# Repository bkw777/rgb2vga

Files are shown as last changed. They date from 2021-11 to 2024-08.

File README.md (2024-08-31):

# rgb2vga
Convert 15khz RGB to 31khz VGA

Uses Altera DE0-Nano FPGA development board to convert analog 15Khz RGB signal to VGA 31Khz 256 color.

This is a modified version of the original [RGB2VGA by Luis Felipe da Costa Antoniosi](https://sites.google.com/site/tandycocoloco/fpga-rgb2vga).  
<!-- (Archived original site [archive.org](https://web.archive.org/web/https://sites.google.com/site/tandycocoloco/rgb2vga)) -->

The electronics and fpga code are the same as the original.

The resistor values are from [Roger Taylor](http://www.cococommunity.net/vga-for-the-coco-3/).

The physical layout is changed to make a more compact package and to build-in the two modifications described in the original docs.

The schematic and pcb layout are re-drawn from scratch in KiCad to provide editable source files.

The VHDL source is just a fork of [the original](https://github.com/lfantoniosi/rgb2vga) but with all of the non-source files cleaned out.  
The VHDL does compile and you can generate a new working rgb2vga.jic from it. But as noted by Roger Taylor, you may want to use the original JIC file from Luis anyway because it may be more stable. There is a preseved copy of Luis's original rgb2vga.jic in [vhdl/Original_JIC](vhdl/Original_JIC).

The enclosure is mine, and the OpenSCAD source is included.

Video showing v003 in action.  
(https://youtu.be/MPYQRHWyUGA)

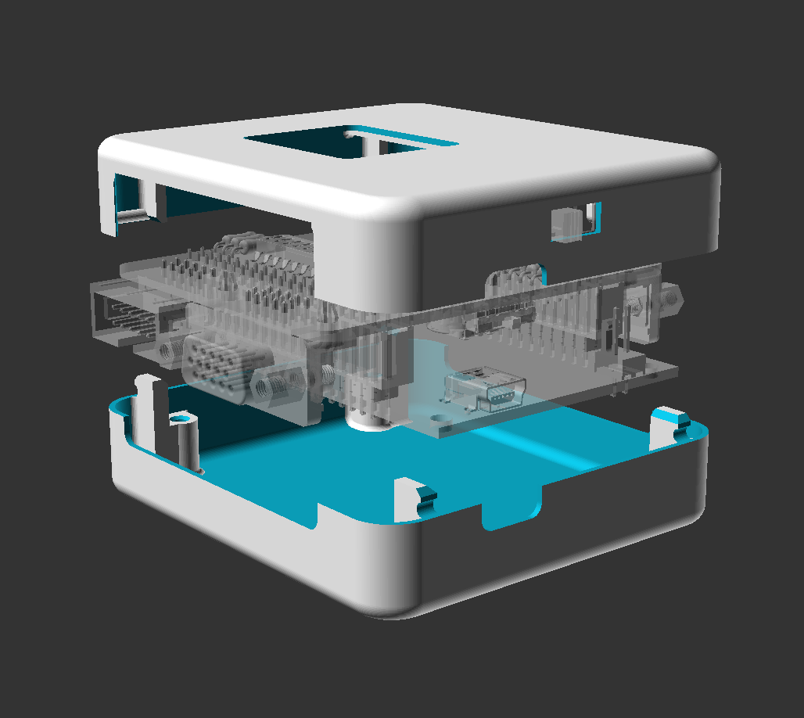
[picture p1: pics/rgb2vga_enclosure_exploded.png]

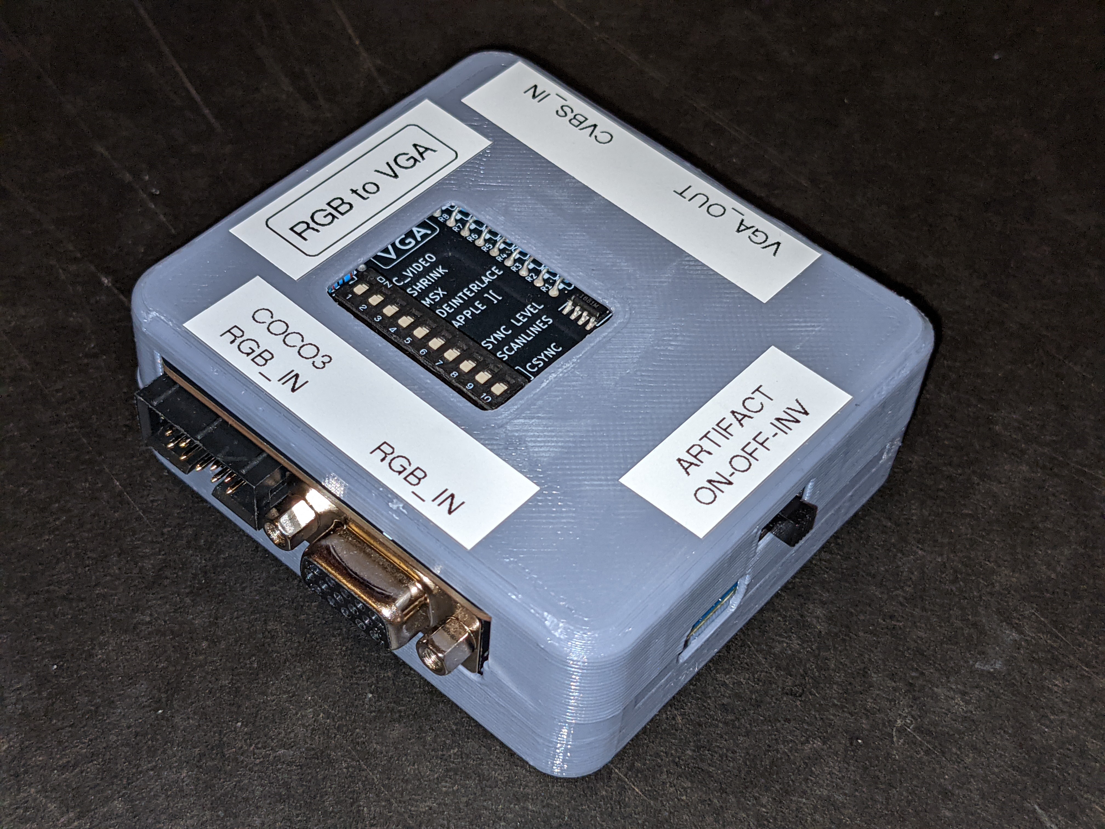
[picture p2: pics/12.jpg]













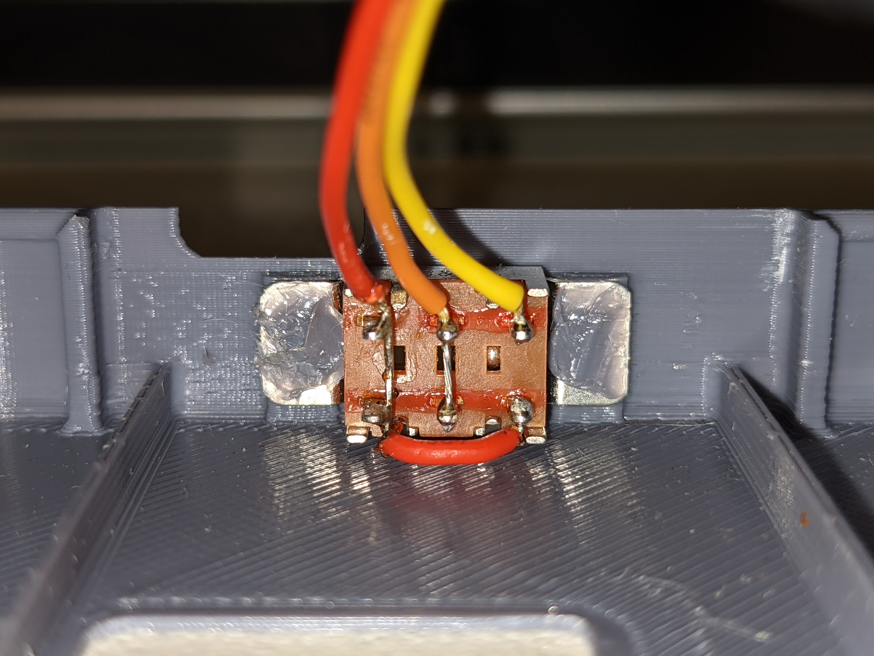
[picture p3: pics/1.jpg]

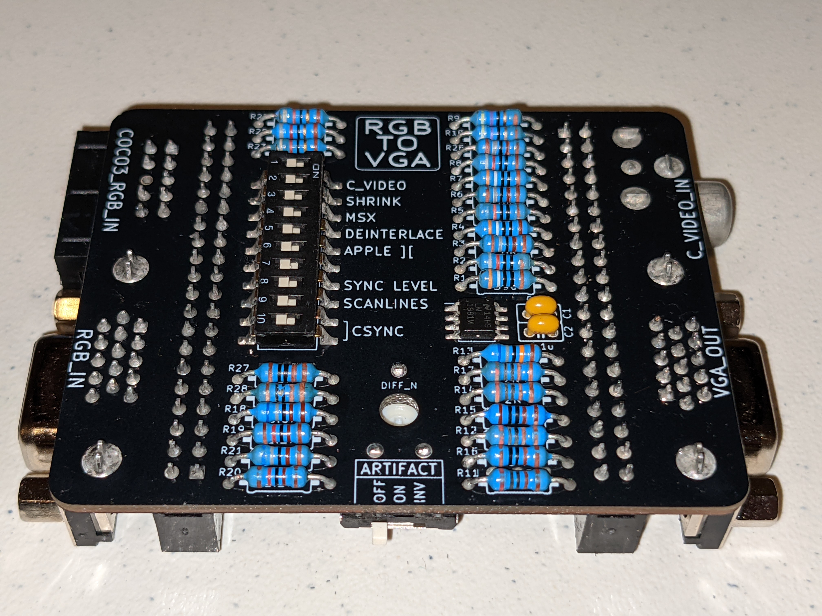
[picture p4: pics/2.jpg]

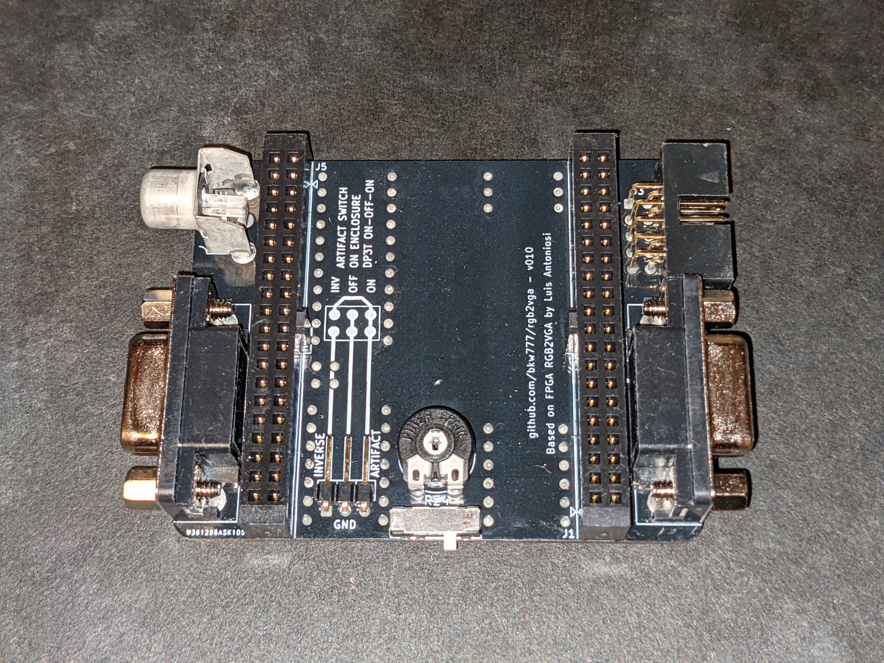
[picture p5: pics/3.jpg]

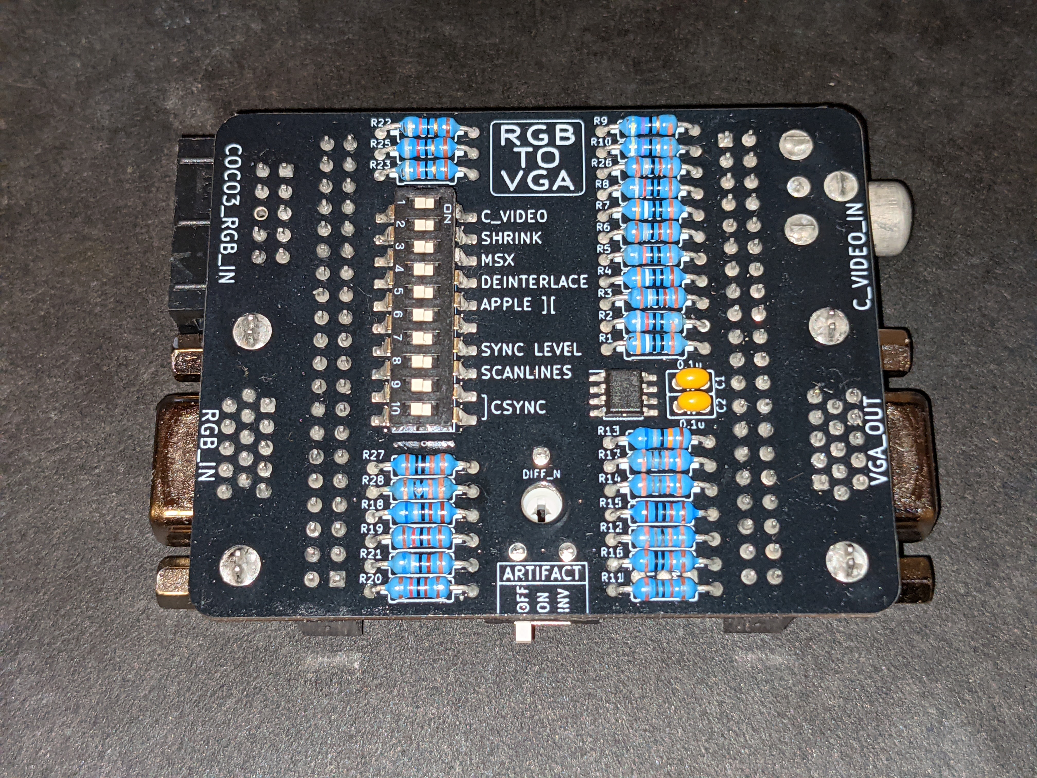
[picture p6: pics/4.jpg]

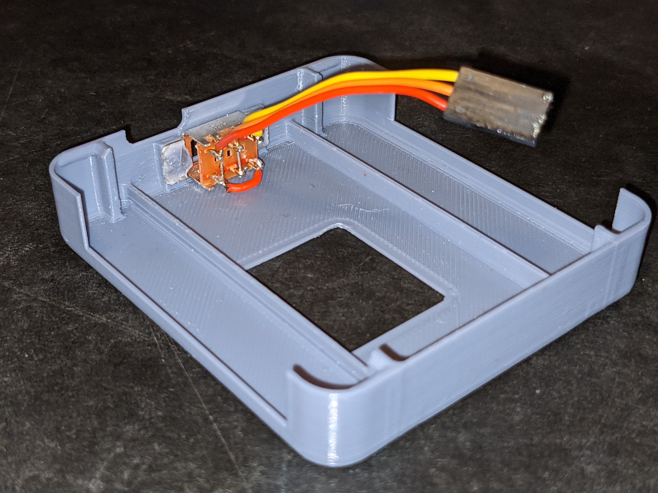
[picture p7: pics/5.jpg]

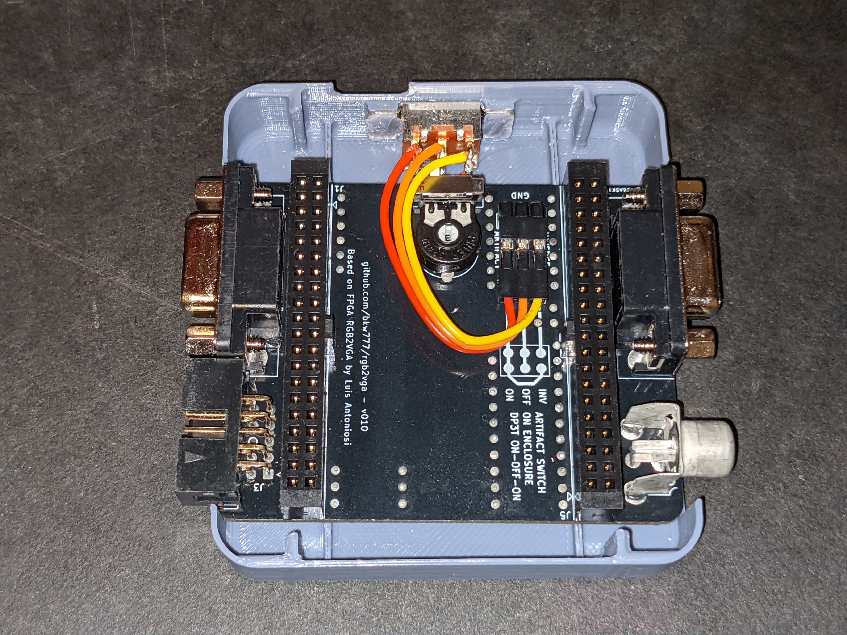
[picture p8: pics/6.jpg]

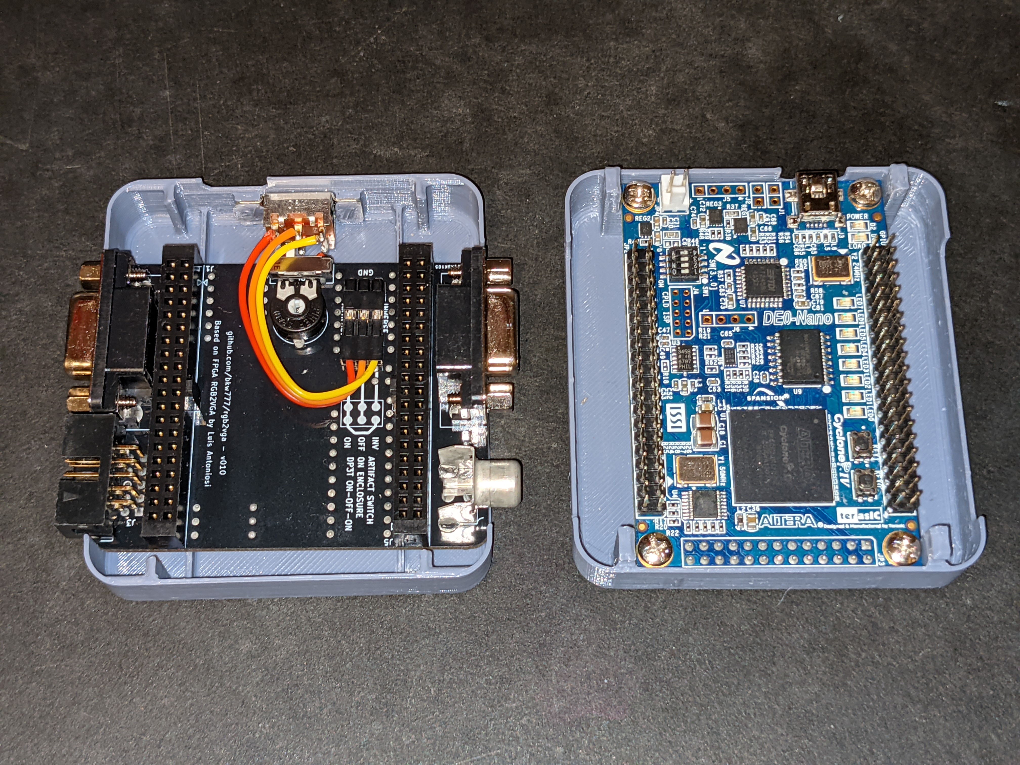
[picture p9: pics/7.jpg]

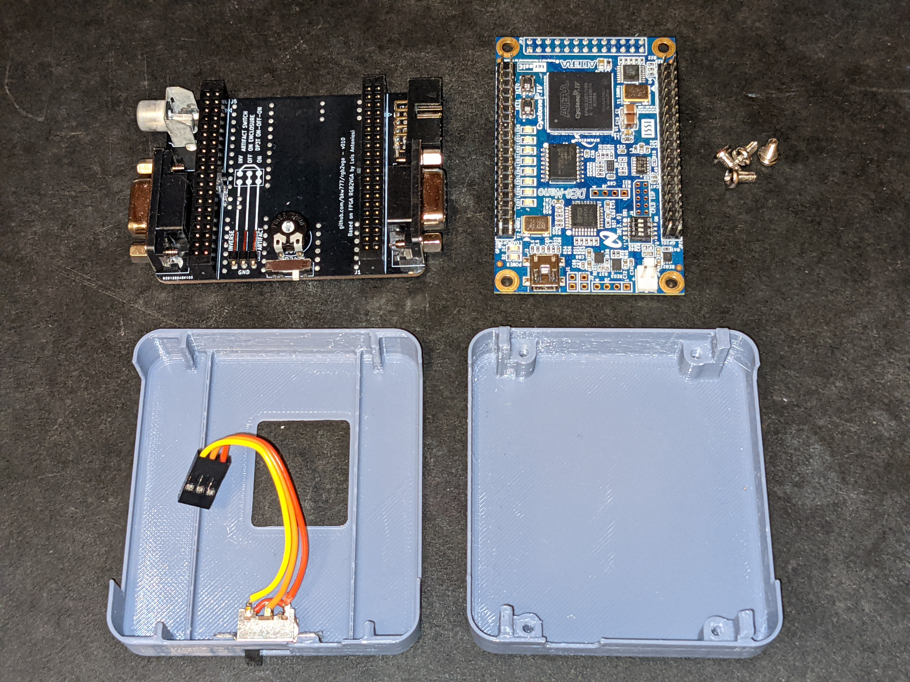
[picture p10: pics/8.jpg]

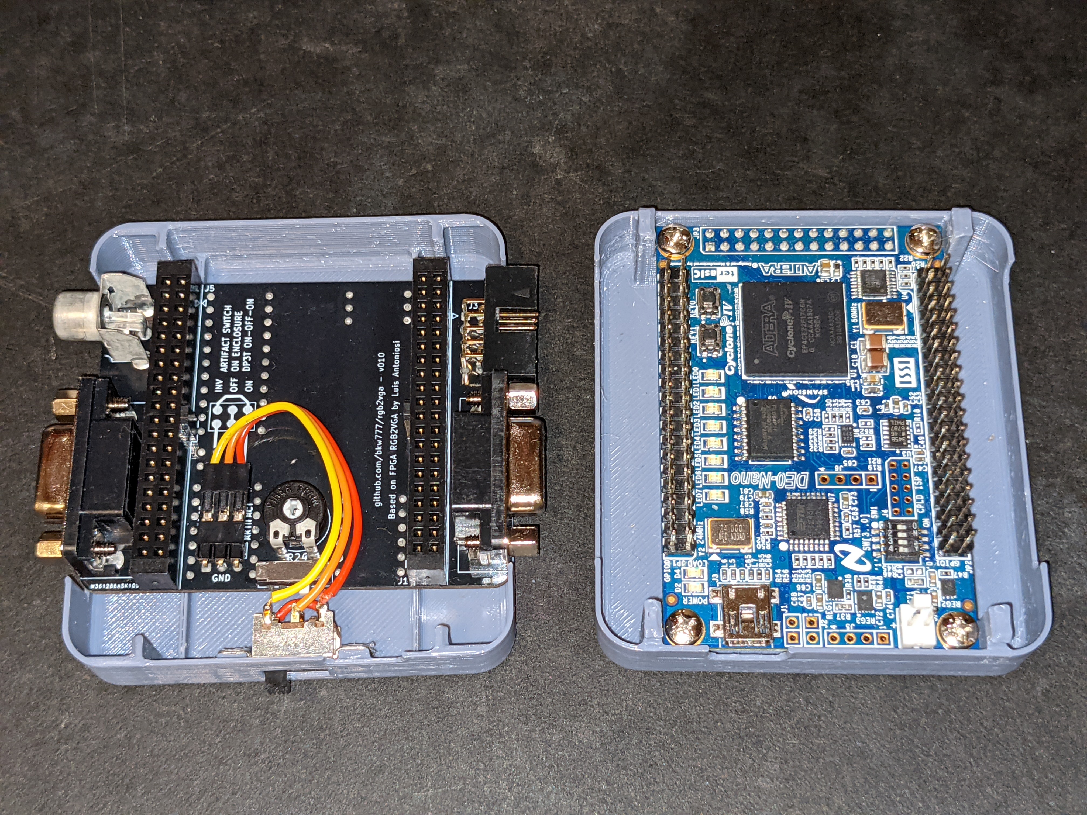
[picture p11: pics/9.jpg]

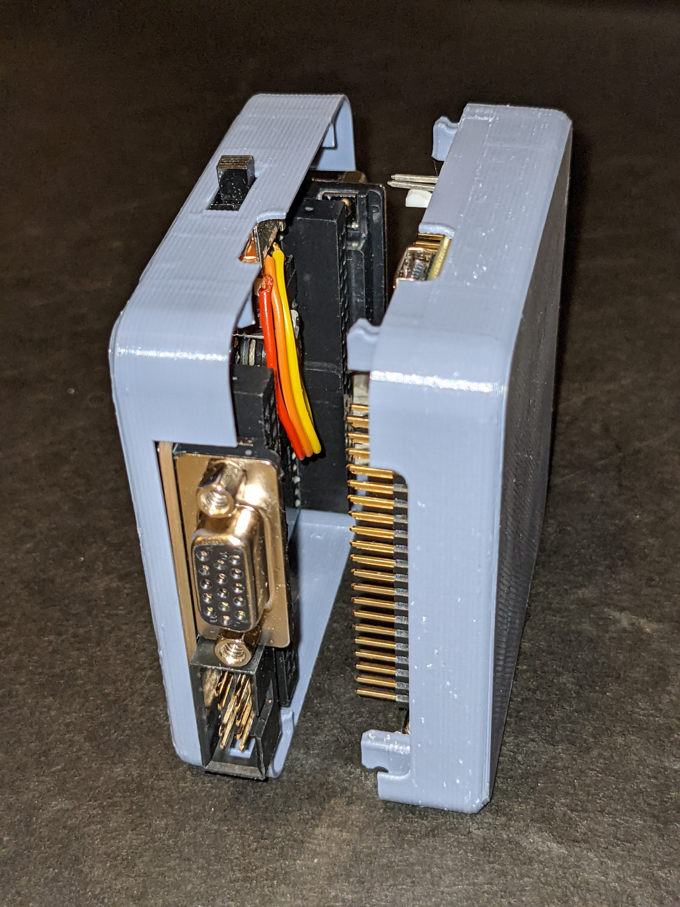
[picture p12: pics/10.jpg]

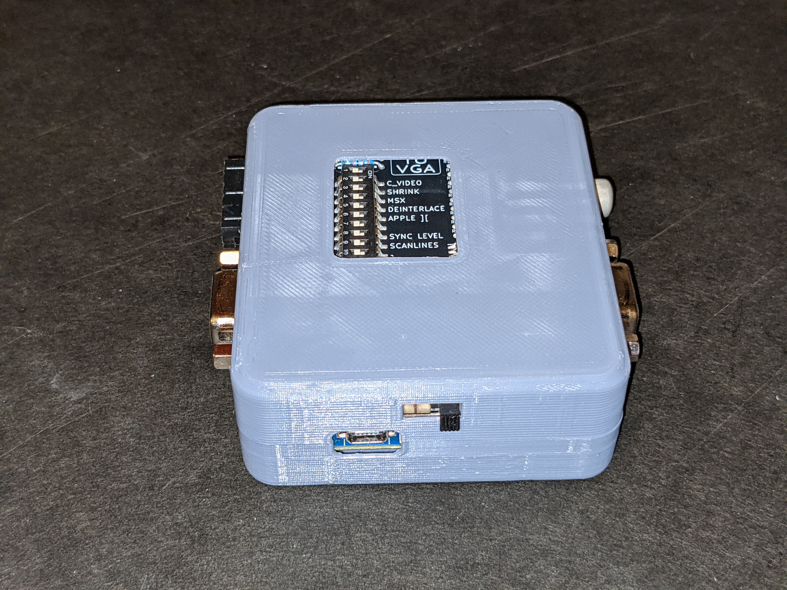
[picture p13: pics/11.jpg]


Alternate enclosure top with screws and nuts for the artifact switch instead of melted posts.
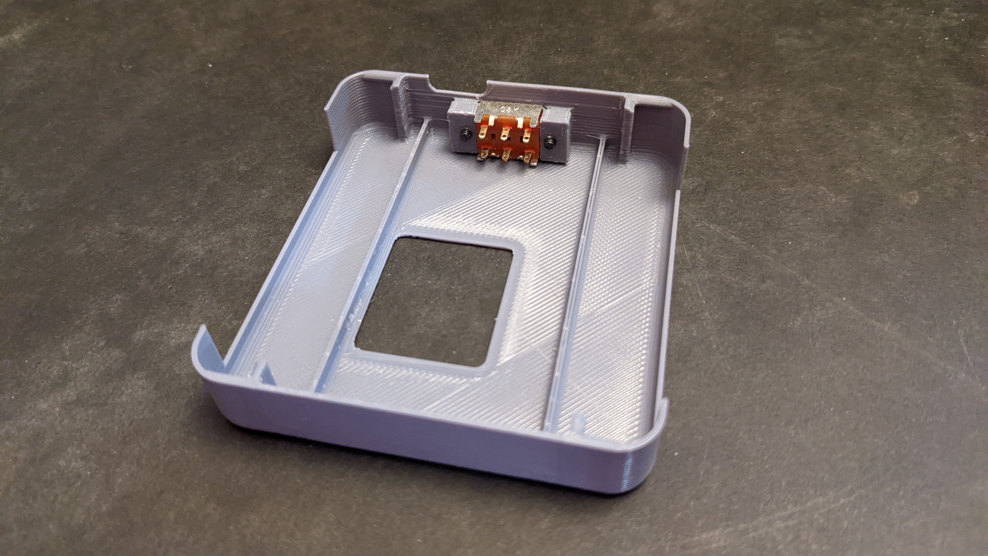
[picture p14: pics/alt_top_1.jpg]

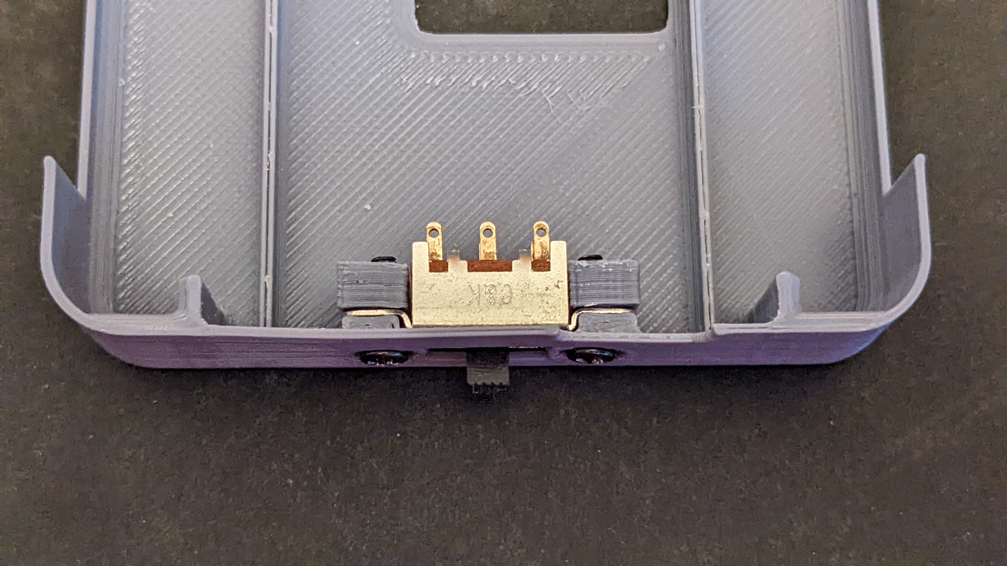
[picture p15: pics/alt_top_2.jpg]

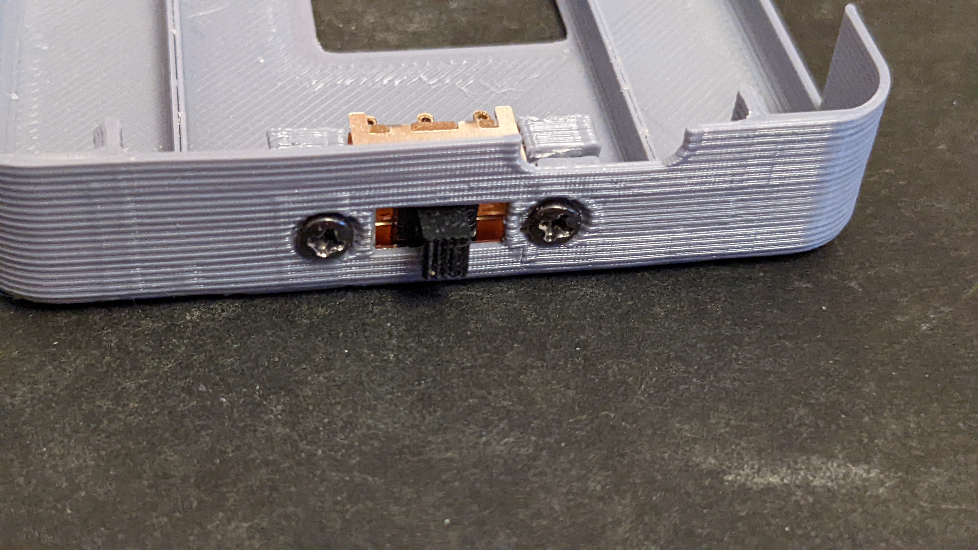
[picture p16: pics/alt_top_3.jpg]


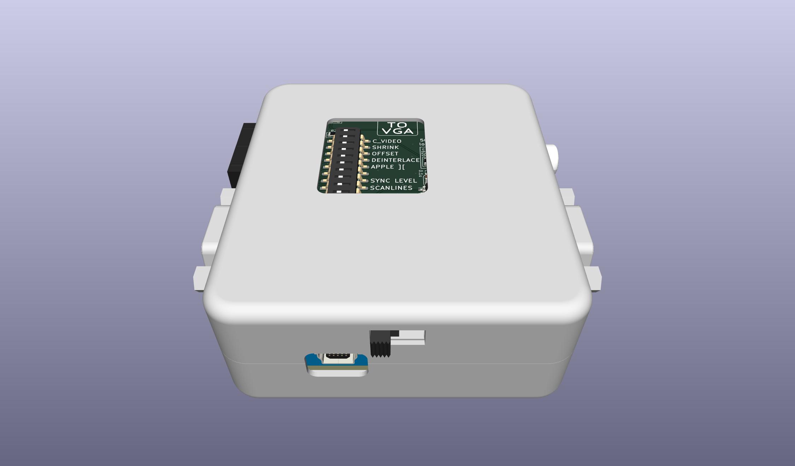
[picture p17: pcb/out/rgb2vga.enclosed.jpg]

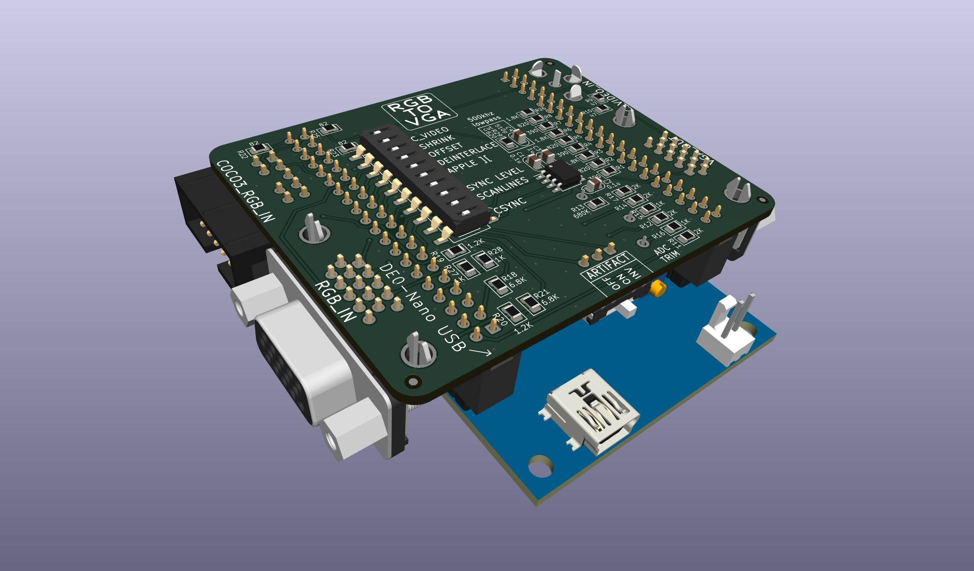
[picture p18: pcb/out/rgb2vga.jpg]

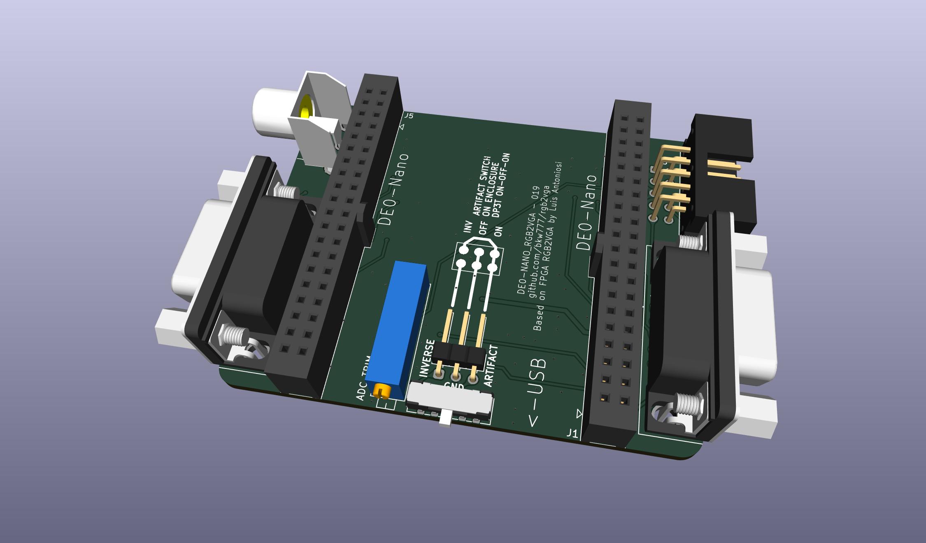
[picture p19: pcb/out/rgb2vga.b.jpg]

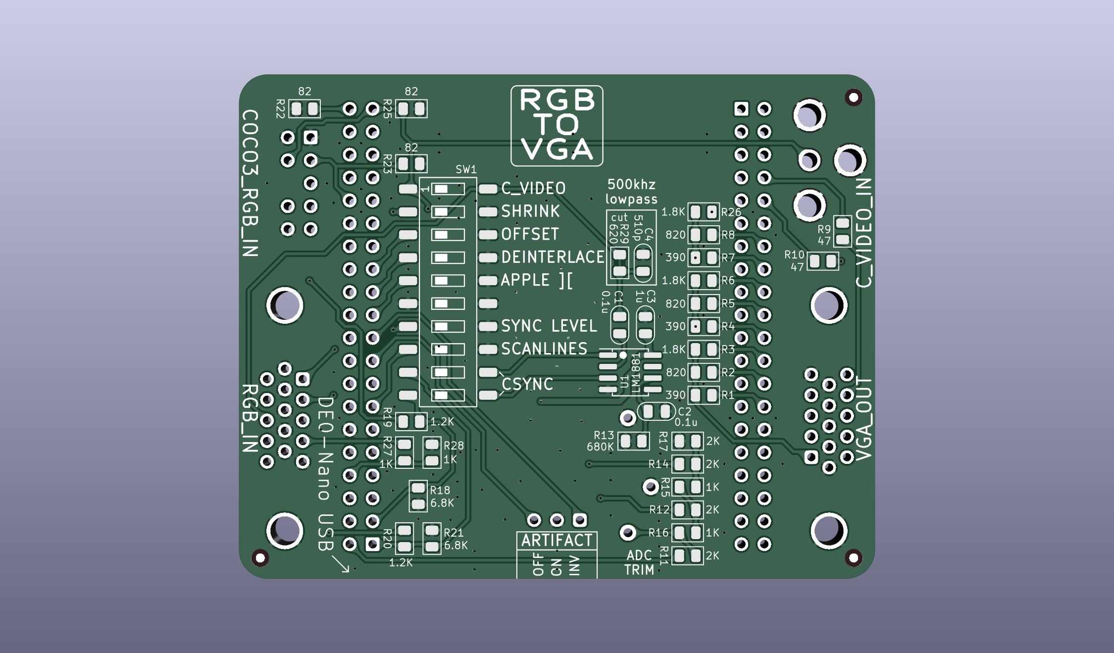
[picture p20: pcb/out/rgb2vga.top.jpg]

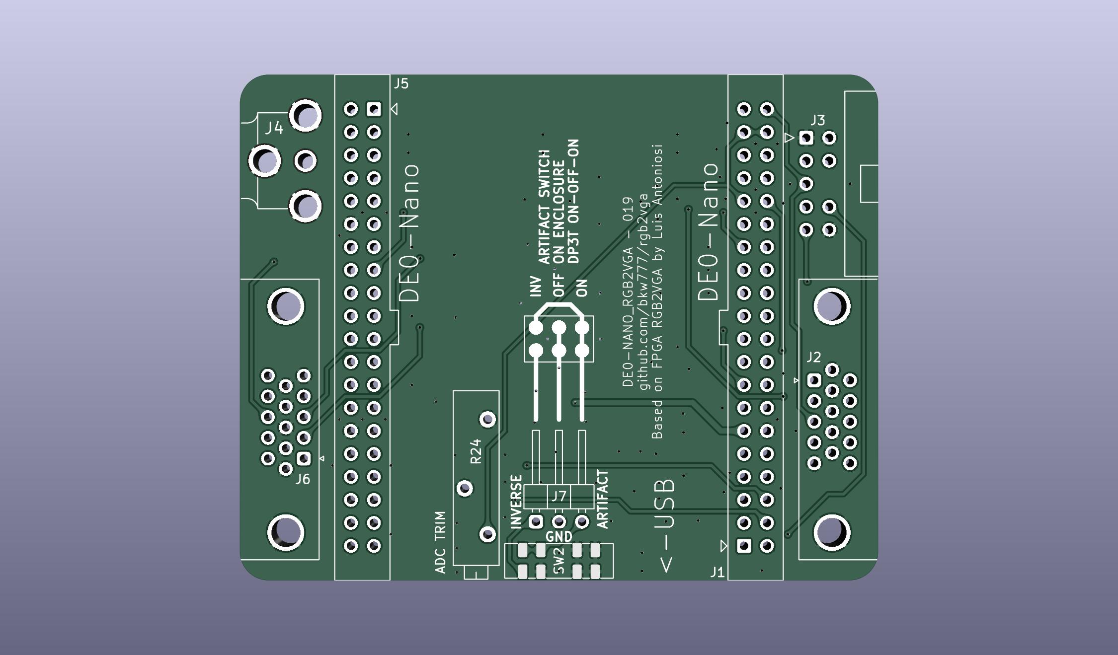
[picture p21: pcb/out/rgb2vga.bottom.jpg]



<!-- [PCB from OSHPark]()  -->
[PCB and Enclosure from PCBWAY](https://www.pcbway.com/project/shareproject/de0_nano_fpga_rgb2vga.html)  

[BOM from DigiKey](https://www.digikey.com/short/wv89d9fv)  

The BOM does not include R29 or C4, which you normally do not populate.  
<!-- 
R29 and C4 provide a 500khz lowpass filter from the LM1881 datasheet.  
If you want to add the lowpass filter, remember to cut the trace in the middle of the R29 footprint.  
I have no idea if the lowpass filter is desired or not. It's in the LM1881 datasheet and it sounds like a good idea since the computer is full of 1+ mhz signals, but I have not actually tested that addition yet.
-->

<!-- 
[DE0-Nano](http://www.terasic.com.tw/cgi-bin/page/archive.pl?Language=English&No=593)
When searching other sources like ebay, don't accidentally get **DE0-Nano-SoC**, that's something else.
-->

<!--
## Through-Hole Version
![](pcb/out/rgb2vga.THT.jpg)
![](pcb/out/rgb2vga.THT.b.jpg)
![](pcb/out/rgb2vga.THT.top.jpg)
![](pcb/out/rgb2vga.THT.bottom.jpg)

[Through-Hole BOM from DigiKey](https://www.digikey.com/short/5mq32b7z)
-->

[PCB Gerbers, FPGA Firmware, Enclosure STLs](../../releases/)

# Directions  
## Building the PCB  
- Remove pin #6 from the 2x5 coco3 rgb connector before soldering. Pin #6 is the center pin on the bottom row, opposite/away from the polarity notch.  
- Solder trim pot R24 on the bottom side, and flush cut and re-flow to smooth domes, before R13, R15, R16.  
- Solder the LM1881 U1 before any of the other parts around it.  
- Solder the Artifact switch SW2 before the 3-pin header J7.  
- Solder remaining parts in any order.  

## Programming the DE0-Nano  
Below is the minimum directions and minimum download possible, using the stand-alone Quartus programmer app and the pre-compiled firmware.  
Alternatively, [compile the firmware from the vhdl source](compile_vhdl.md).

### Install the Quartus Standalone Programmer  
https://fpgasoftware.intel.com/  
Select edition: Lite -> Additional Software -> Quartus Prime Programmer and Tools  
(For Linux, install: Individual Files -> Quartus Prime, not the stand-alone programmer package. The stand-alone Quartus programmer package for Linux is broken, missing ```libprotobuf.so.14.0.0```)

### Download the firmware
Download ```rgb2vga.jic``` from [releases](../../releases/)  

### Program the DE0-Nano  
Connect the usb cable  
Launch the Quartus Programmer app  
Hardware Setup... -> USB-Blaster  
Add File... -> ```rgb2vga.jic```  
Tick "Program/Configure"  
Start  

## Assemble
- Remove the acrylic cover and short upper stand-offs from the DE0-Nano. If using the printed enclosure, remove the lower stand-offs too. If not using the printed enclosure, keep the longer bottom standoffs, replace the short upper standoffs with the screws from the cover.  
- Put the RGB2VGA and DE0-Nano together with the trim pot on the same side as the USB connector.  
- For TANDY Color Computer 3, turn all dip switches off. For most games, turn the Artifact switch on. If using the printed enclosure with enclosure artifact switch, set the pcb artifact switch to OFF.  
- Turn the trim pot to 50%.  
- Insert the IDC pin block-off plugs into pin #6 on each end of the ribbon cable. Pin #6 is the center pin on the row opposite/away from the the polarity bump.  

## Enclosure
The source for the enclosure is the [rgb2vga.scad](case/rgb2vga.scad) OpenSCAD file.

The bottom part of the enclosure has screw holes that will accept the M3 screws that came on the rgb2vga, but the screws are not needed. You can simply remove all hardware parts from the DE0-Nano, put the DE0-Nano + rgb2vga in the case and snap it together.

## Artifact Switch
Cut the 3-pin female jumper cable in half. Set one half aside, it won't be used.

Take one half and solder the cut ends to the slide switch as per the diagram on the silk screen on the bottom of the PCB.

Place the switch onto the posts inside the top cover.  
There will be excess plastic underneath the two mounting posts, preventing the switch from seating flat.  
Just heat the switch flanges with the soldering iron to melt the switch into place flat to the inside wall.

Melt the posts with a soldering iron to secure the switch to the top cover.  

Plug the remaining 3-pin female plug onto the 3-pin male header on the pcb.  

Set the small artifact switch on the pcb to the "OFF" position before closing up the enclosure.

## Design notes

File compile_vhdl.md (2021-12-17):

## Programming the DE0-Nano from source  

### Install Quartus  
https://fpgasoftware.intel.com/  
Select edition: Lite -> Individual Files  
Download these two parts:  
- Quartus Prime  
- Cyclone IV device support

Install the Qartus Prime package, and it will pick up the Cyclone IV package itself.  
Installation help: https://github.com/Jefferson-Lopes/quartus-installation

### Compile the VHDL  
Connect the usb cable  
Start Quartus  
Open Project -> ```vhdl/rgb2vga.qpf```  
Processing -> Start Compilation  

This produces the file: ```output_files/rgb2vga.sof```

File -> Convert Programming Files...  
Open Conversion Setup Data... -> ```DE0-Nano.cof  ```
Generate  
Close  

This produces the file: ```output_files/rgb2vga.jic```

### Program the DE0-Nano  
Tools -> Programmer  
Hardware Setup... -> USB-Blaster  (should be already autodetected)  
Delete any entries pre-loaded in the middle section (probably has ```output_files/rgb2vga.sof```)  
Add File... -> ```output_files/rgb2vga.jic```  
Tick "Program/Configure"  
Start  

## The DE0-Nano is now programmed

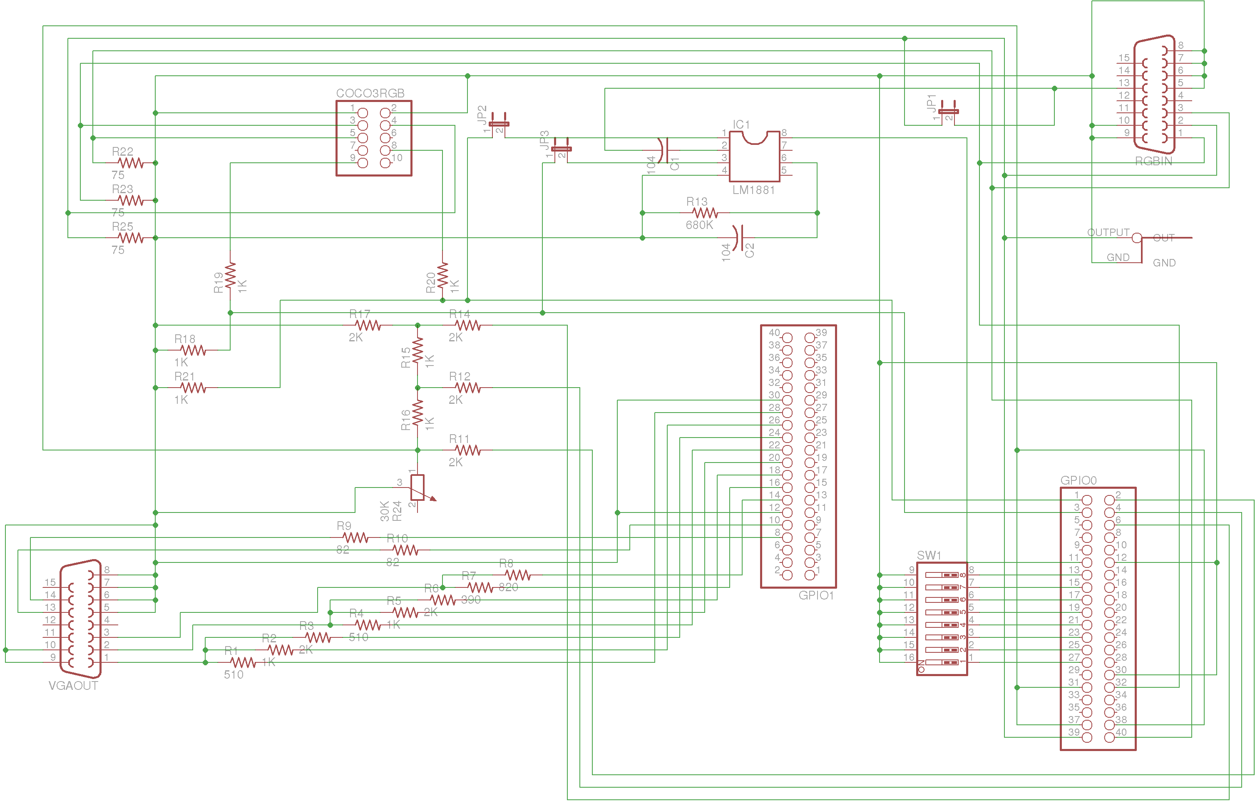
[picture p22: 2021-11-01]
ref/schematic.png

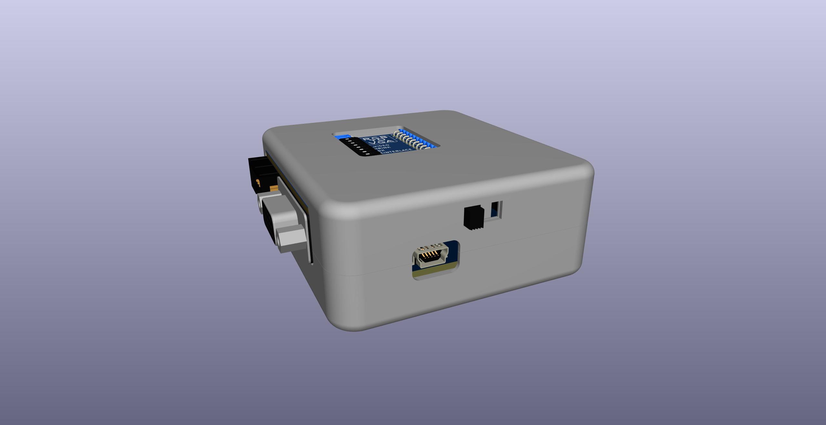
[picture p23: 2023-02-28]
pics/rgb2vga_3.jpg

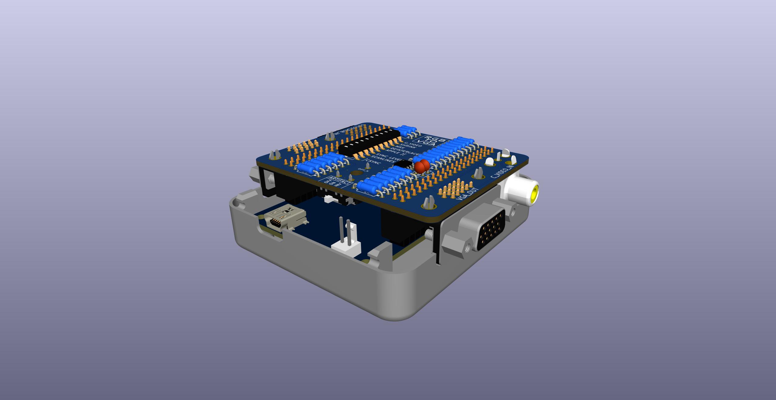
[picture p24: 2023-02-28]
pics/rgb2vga_10.jpg

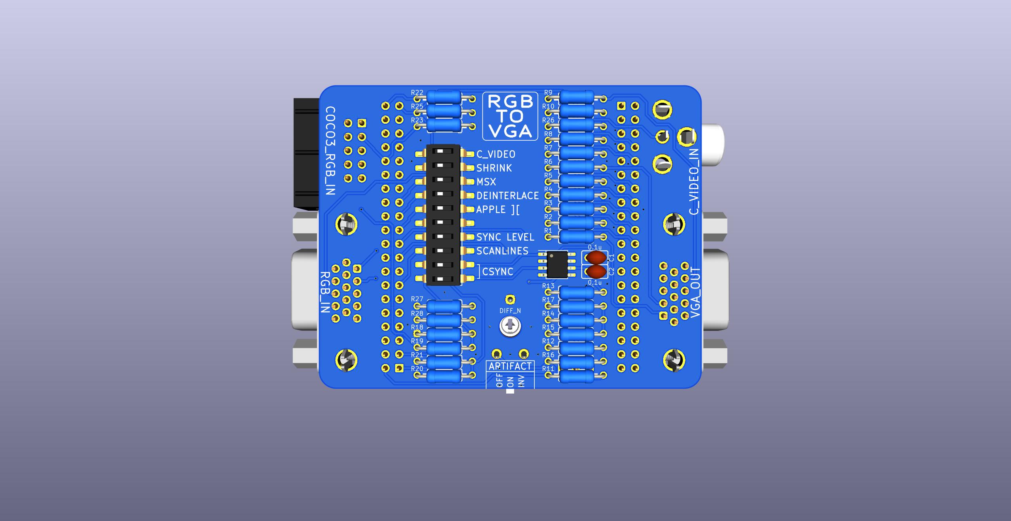
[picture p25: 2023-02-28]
pics/rgb2vga_4.jpg

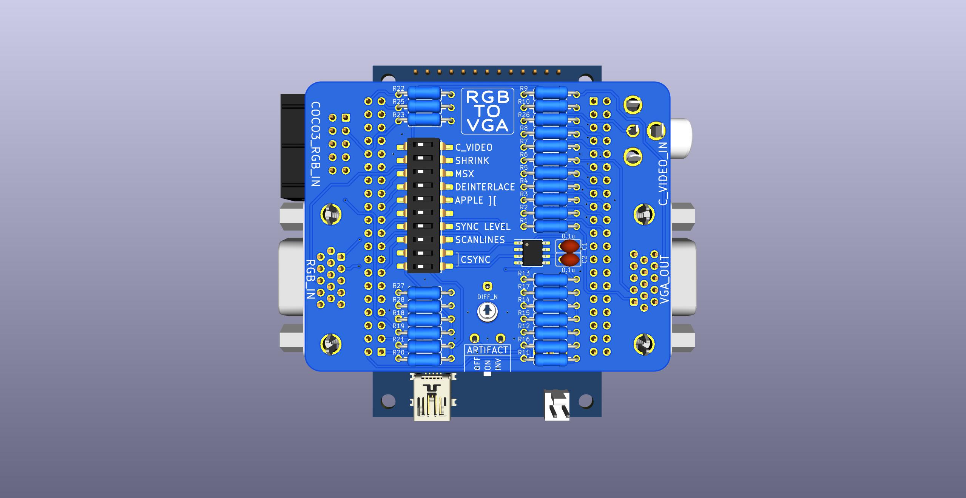
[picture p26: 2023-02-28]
pics/rgb2vga_5.jpg

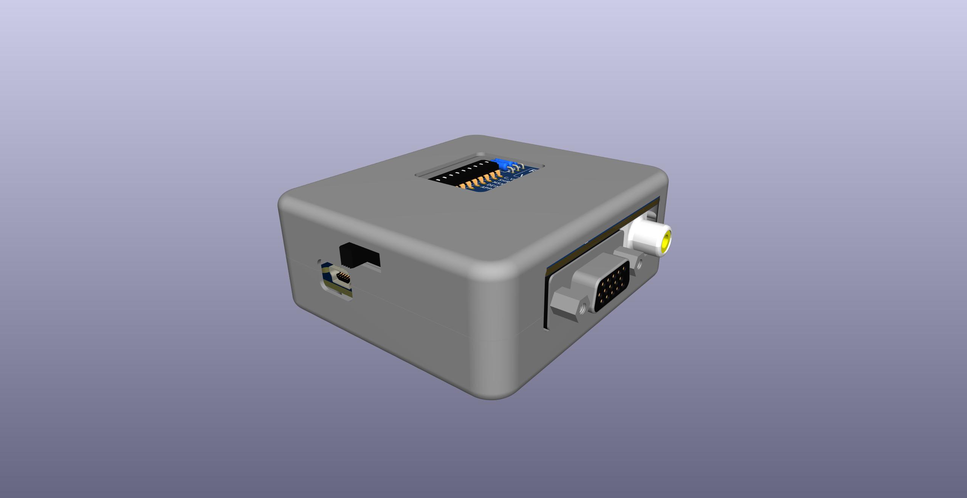
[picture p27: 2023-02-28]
pics/rgb2vga_11.jpg

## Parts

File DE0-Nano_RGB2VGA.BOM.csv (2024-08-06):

Index | Quantity | Part Number | Manufacturer Part Number | Description | Customer Reference | Available | Backorder | Unit Price | Extended Price USD
1 | 3 | P82DACT-ND | ERA-6AEB820V | RES SMD 82 OHM 0.1% 1/8W 0805 |  | 3 | 0 | 0.13000 | 0.39
2 | 1 | 1276-1066-1-ND | CL21B105KAFNNNE | CAP CER 1UF 25V X7R 0805 |  | 1 | 0 | 0.10000 | 0.10
3 | 2 | P1.2KDACT-ND | ERA-6AEB122V | RES SMD 1.2K OHM 0.1% 1/8W 0805 |  | 2 | 0 | 0.13000 | 0.26
4 | 3 | P390DACT-ND | ERA-6AEB391V | RES SMD 390 OHM 0.1% 1/8W 0805 |  | 3 | 0 | 0.13000 | 0.39
5 | 3 | P820DACT-ND | ERA-6AEB821V | RES SMD 820 OHM 0.1% 1/8W 0805 |  | 3 | 0 | 0.13000 | 0.39
6 | 2 | P47DACT-ND | ERA-6AEB470V | RES SMD 47 OHM 0.1% 1/8W 0805 |  | 2 | 0 | 0.13000 | 0.26
7 | 3 | P1.8KDACT-ND | ERA-6AEB182V | RES SMD 1.8K OHM 0.1% 1/8W 0805 |  | 3 | 0 | 0.13000 | 0.39
8 | 1 | Q1252-ND | QFWC-05-05 | AC/DC WALL MOUNT ADAPTER 5V 5W |  | 1 | 0 | 4.82000 | 4.82
9 | 1 | Q1256-ND | 3021095-06 | CBL USB2.0 A PLUG-MIN B PLUG |  | 1 | 0 | 4.22000 | 4.22
10 | 2 | P6.8KDACT-ND | ERA-6AEB682V | RES SMD 6.8K OHM 0.1% 1/8W 0805 |  | 2 | 0 | 0.13000 | 0.26
11 | 1 | 296-47437-1-ND | LM1881MX/NOPB | IC VIDEO SYNC SEPARATOR 8SOIC |  | 1 | 0 | 3.07000 | 3.07
12 | 2 | S9200-ND | SFH11-PBPC-D20-ST-BK | CONN HDR 40POS 0.1 GOLD PCB |  | 2 | 0 | 1.96000 | 3.92
13 | 1 | CKN9548-ND | OS203013MT7QN1 | SWITCH SLIDE DPDT 300MA 30V |  | 1 | 0 | 1.08000 | 1.08
14 | 1 | S1111EC-03-ND | PRPC003SBAN-M71RC | CONN HEADER R/A 3POS 2.54MM |  | 1 | 0 | 0.12000 | 0.12
15 | 2 | 478-KGM21NR71H104JTCT-ND | KGM21NR71H104JT | CAP CER 0.1UF 50V X7R 0805 |  | 2 | 0 | 0.19000 | 0.38
16 | 1 | 563-1352-1-ND | CL-SB-23A-11T | SWITCH SLIDE DP3T 200MA 12V |  | 1 | 0 | 1.58000 | 1.58
17 | 2 | 2057-HD15-SN-25-ND | HD15-SN-25 | CONN D-SUB HD RCPT 15P R/A SLDR |  | 2 | 0 | 2.32000 | 4.64
18 | 1 | 3006P-103LF-ND | 3006P-1-103LF | TRIMMER 10KOHM 0.75W PC PIN SIDE |  | 1 | 0 | 2.10000 | 2.10
19 | 1 | A3DDH-1036G-ND | A3DDH-1036G | IDC CABLE - AKR10H/AE10G/AKR10H |  | 0 | 1 | 7.54000 | 7.54
20 | 2 | ASKP01-ND | 499712-1 | CONN KEYING PLUG BLACK |  | 2 | 0 | 0.21000 | 0.42
21 | 1 | ED10533-ND | 302-R101 | CONN HEADER R/A 10POS 2.54MM |  | 1 | 0 | 0.53000 | 0.53
22 | 1 | 1568-1930-ND | PRT-10368 | JUMPER WIRE 0.1" 3-PIN 6" |  | 1 | 0 | 1.60000 | 1.60
23 | 1 | 2223-DS04-254-2-10BK-SMT-ND | DS04-254-2-10BK-SMT | SWITCH SLIDE DIP SPST 0.025A 24V |  | 1 | 0 | 0.92000 | 0.92
24 | 4 | P1.0KDACT-ND | ERA-6AEB102V | RES SMD 1K OHM 0.1% 1/8W 0805 |  | 4 | 0 | 0.13000 | 0.52
25 | 1 | P0082-ND | P0082 | DE0-NANO EVAL BOARD |  | 1 | 0 | 114.96000 | 114.96
26 | 1 | CP-1403-ND | RCJ-014 | CONN RCA JACK MONO 3.2MM R/A |  | 1 | 0 | 0.96000 | 0.96
27 | 4 | P2.0KDACT-ND | ERA-6AEB202V | RES SMD 2K OHM 0.1% 1/8W 0805 |  | 4 | 0 | 0.13000 | 0.52
28 | 1 | P680KDACT-ND | ERA-6AEB684V | RES SMD 680K OHM 0.1% 1/8W 0805 |  | 1 | 0 | 0.13000 | 0.13

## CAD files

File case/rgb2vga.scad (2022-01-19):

/* 3d-printable enclosure for github.com/bkw777/rgb2vga - v009 */
// Version: 012

// This file contains both the top and bottom case parts.
// The "view = ..." setting below selects which part to render for STL export for printing,
// or shows both parts exploded or both parts together for viewing.

// "closed" = show both top & bottom shells and pcb model
// "explode" = show both top & bottom shells, seperated by explode_seperation, and pcb model
// "top" = show top shell alone, rotated and translated for FDM printing
// "bottom" = show bottom shell alone, rotated and translated for FDM printing
view = "explode";

// customizable options

// switch_type
// 0 = no switch
// 1 = OS203013MT7QN1 on meltable posts
// 2 = OS203013MT7QN1 with screw holes, M2.5x8 flat head screws, and printed nuts
// 3 = OS203013MT7QN1 with screw holes, M2.5x8 wafer head screws, and printed nuts
switch_type = 1;

// Printing process: "FDM", "SLS"
// The ID of screw holes needs to be adjusted depending on whether the model is printed by FDM or SLS.
// Holes come out slightly undersized with FDM. A hole the right size for a given screw when printed by FDM, will be too large when printed by SLS.
// So this setting adjusts the ID of screw holes to be optimal for the specified printing method.
printing_process = "FDM"; // FDM or SLS, adjusts ID of screw holes

include_text = (printing_process=="SLS") ? true : false;

explode_seperation = 30;
wall_thickness = 1;

text_depth = 0.2;
text_size_1 = 3.2;
text_size_2 = 5.5;

fc = 0.2;  // fitment clearance
inner_corner_h = 6;  // main shell inside corner horizontal radius
inner_corner_v = 2;  // main shell inside corner vertical radius
df = 1;  // default fillet

// diameter of hole for M3 screw, but not needed
pcb_mount_screw_d = 3;
pcb_mount_post_id_fdm = pcb_mount_screw_d * 0.85;
pcb_mount_post_id_sls = pcb_mount_screw_d * 0.8;
pcb_mount_post_id = (printing_process=="SLS") ? pcb_mount_post_id_sls : pcb_mount_post_id_fdm;

pcb_mount_post_wall = 1.8;
pcb_mount_post_od = pcb_mount_post_id + pcb_mount_post_wall*2;

// arc smoothness
$fs = 0.2;
$fa = 1;

// To create pcb.stl:
//  pcbnew: export pcb.step
//  freecad: import pcb.step, export pcb.stl
// Both files are huge, exclude from git.
pcb_model_stl = "pcb.stl";

pcb_thickness = 1.6;
space_above = 4;       // rgb2vga pcb top to inside wall ceiling
space_between = 11.25; // de0nano pcb top to rgb2vga pcb bottom
space_below = 10;      // inside wall floor to de0nano pcb bottom

// difference between de0-nano center and rgb2vga center
pcb_centers_offset = 2.7;   // from pcbnew

de0nano_pcb_length = 75.4;
de0nano_pcb_width = 49.2;
de0nano_pcb_elev = space_below;
de0nano_pcb_mount_l = 68.6; // from pcbnew
de0nano_pcb_mount_w = 42.4; // from pcbnew

rgb2vga_pcb_length = 70.48; // from pcbnew
rgb2vga_pcb_width = 55.88;  // from pcbnew
rgb2vga_pcb_corner = 3.175; // from pcbnew
rgb2vga_pcb_elev = de0nano_pcb_elev + pcb_thickness + space_between;

port_gap = 1; // gap around port connectors
port_corner = port_gap; // inside corner radius around port connectors

inner_height = space_below + pcb_thickness + space_between + pcb_thickness + space_above;
outer_height = wall_thickness + inner_height + wall_thickness;

pcb_model_elev = rgb2vga_pcb_elev;

// LENGTH - outer length flush with rgb2vga pcb length
outer_length = rgb2vga_pcb_length; // outside flush with rgb2vga pcb
inner_length = outer_length - wall_thickness - wall_thickness;

// WIDTH - inner width larger than de0-nano pcb length
inner_width = fc + de0nano_pcb_length + fc; // inside fit to de0-nano pcb
outer_width = wall_thickness + inner_width + wall_thickness;

window_height = 28;
window_width = 23.5;
window_corner = 2;
window_pos_x = -5.3;
window_pos_y = 6.505;

usb_width = 7.8;
usb_height = 4.1;
usb_gap = 1 + port_gap;
usb_corner = max(0.1,usb_gap);

hd15_height = 12.6;
ports_width = rgb2vga_pcb_width - 3.5;
ports_height = hd15_height + pcb_thickness; // + pcb_thickness;
ports_gap = fc;
ports_corner = 2;
ports_elev = rgb2vga_pcb_elev-ports_height/2+pcb_thickness;

split_elev = outer_height/2; // where to cut for top & bottom parts

clip_width = 3;
clip_depth = 6;
clip_height = 4;
clip_detent = 1;

reg_post_width = 2;
reg_post_depth = 4;

top_ribs_loc = 18.85; // 18.85 inside, 21.7 gpio, 25.3 outside
top_ribs_width = 1;

rca_pin_l = 18.41;
rca_pin_i = 2.75;
rca_pin_r = 1.8;
rca_pin_h = 3;

// artifact/inverse switch
// switch_type == 1 or 2
// type 1 - C&K OS203013MT7QN1 on melt-able posts
sw1_model_stl = "CK_OS203013MT7QN1.stl";
sw1_sheet_thickness = 0.5;
sw1_body_z = 9.9;
sw1_body_tl = 24;
sw1_body_l = 14.2;
sw1_body_ml = 12.6;
sw1_pos_x = 0;
sw1_pos_y = sw1_sheet_thickness - inner_width/2 + fc;
sw1_pos_z = inner_height - sw1_body_z/2 - fc;
sw1_hole_l = 9.7;
sw1_hole_h = 4.3;
sw1_post_dx = 2.8;
sw1_post_dz = 4.4;
sw1_post_mx = 17 / 2; // posts 17 center-center
sw1_wing_setback = 2; // center front to wing rear, includes wing sw_sheet_thickness
sw1_wing_z = 8.4;
sw1_wing_x = (sw1_body_tl - sw1_body_l) / 2;
// type 2 - C&K OS203013MT7QN1 on M2.5x8 flat head screws & printed nuts
sw2_screw_model_stl = "M2.5x8_flat.stl";
sw2_screw_d = 2.5;
sw2_screw_l = 8;
sw_nut_thickness = 4;
sw_nut_width = (sw1_body_tl-sw1_body_ml)/2;
sw_nut_chamfer = 0.5;
sw_nut_id_fdm = sw2_screw_d * 0.95;
sw_nut_id_sls = sw2_screw_d * 0.85;
sw_nut_id = (printing_process=="SLS") ? sw_nut_id_sls : sw_nut_id_fdm;
// type 3 - C&K OS203013MT7QN1 on M2.5x8 wafer head screws & printed nuts
sw3_screw_head_d = 5.75; // wafer head countersink diameter
sw3_screw_head_t = 0.8; // wafer head countersink depth

o = 0.01; // overlap / overcut - ensure union parts overlap and cuts cupletely cut

include <handy.scad>;

module de0nano_pcb_clearance () {
  l = fc + de0nano_pcb_length + fc;
  w = fc + de0nano_pcb_width + fc;
  h = fc + pcb_thickness + fc;
  translate([-w/2,-l/2,-fc+wall_thickness+de0nano_pcb_elev])
   cube([w,l,h]);
}

module rgb2vga_pcb_clearance (tall=true) {
  h = (tall) ? rgb2vga_pcb_elev+pcb_thickness+fc : fc+pcb_thickness+fc ;
  e = (tall) ? wall_thickness : wall_thickness+rgb2vga_pcb_elev-fc ;
  translate([0,pcb_centers_offset,e])
   hull()
    mirror_copy([0,1,0])
     translate([0,rgb2vga_pcb_width/2-rgb2vga_pcb_corner,0])
      mirror_copy([1,0,0])
       translate([rgb2vga_pcb_length/2-rgb2vga_pcb_corner,0,0])
        cylinder(h=h,r=rgb2vga_pcb_corner+fc);
}

module main_ports () {
  pw = (ports_gap+ports_width+ports_gap)/2-ports_corner;
  ph = (ports_gap+ports_height+ports_gap)/2-ports_corner;
  translate([-outer_length/2-o,pcb_centers_offset,wall_thickness+ports_elev])
   rotate([90,0,90])
    hull()
     mirror_copy([0,1,0])
      translate([0,ph,0])
       mirror_copy([1,0,0])
        translate([pw,0,0])
         cylinder(h=o+outer_length+o,r=ports_corner);
}

module usb_port () {
  w = (usb_gap+usb_width+usb_gap)/2-usb_corner;
  h = (usb_gap+usb_height+usb_gap)/2-usb_corner;
  translate([-11.5,-outer_width/2-o,wall_thickness+de0nano_pcb_elev+pcb_thickness+usb_height/2])
   rotate([-90,0,0])
    hull()
     mirror_copy([0,1,0])
      translate([0,h,0])
       mirror_copy([1,0,0])
        translate([w,0,0])
         cylinder(h=o+wall_thickness+o,r=usb_corner);
}

module rca_pin_clearance() {
  translate([rgb2vga_pcb_length/2-rca_pin_i,rca_pin_l+pcb_centers_offset,wall_thickness+rgb2vga_pcb_elev+pcb_thickness+rca_pin_h/2-o])
   cylinder(h=rca_pin_h/2,r1=rca_pin_r+fc,r2=(rca_pin_r+fc)/2);
  translate([rgb2vga_pcb_length/2-rca_pin_i,rca_pin_l+pcb_centers_offset,wall_thickness+rgb2vga_pcb_elev+pcb_thickness])
   cylinder(h=rca_pin_h/2,r=rca_pin_r+fc);
}

module top_window () {
  w = window_width/2-window_corner;
  h = window_height/2-window_corner;
  translate([window_pos_x,window_pos_y,outer_height-wall_thickness-o]) {
   // window
   hull()
    mirror_copy([0,1,0])
     translate([0,h,0])
      mirror_copy([1,0,0])
       translate([w,0,0])
        cylinder(h=o+wall_thickness+o,r=window_corner);
   // "window frame" chamfer - not worth it if wall is thin
   if (wall_thickness>=1.5)
    hull()
     mirror_copy([0,1,0])
      translate([0,h,0])
       mirror_copy([1,0,0])
        translate([w,0,-1.6])
         cylinder(h=window_corner*2,r1=0,r2=window_corner*2);
   }
}

module pcb_model () {
 translate([0,pcb_centers_offset,wall_thickness+pcb_model_elev])
  import(pcb_model_stl);
  //#de0nano_pcb_clearance();
  //#rgb2vga_pcb_clearance(false);
}
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

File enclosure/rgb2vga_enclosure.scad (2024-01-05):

/* 3d-printable enclosure for github.com/bkw777/rgb2vga */
// version: 014

// This file contains both the top and bottom case parts.
// The "make = ..." setting below selects which part(s) to view/output.

// "closed" = show both top & bottom shells and pcb model
// "explode" = show both top & bottom shells, seperated by explode_seperation, and pcb model
// "top" = show top shell, meltable bosses for switch, rotated and translated for 3D printing
// "alttop" = like "top", but screw holes & nuts for switch
// "bottom" = show bottom shell alone, rotated and translated for FDM printing
// "nut" = one nut alone
make = "explode";

// customizable options

// How do you want to mount the Artifact/Inverse slide switch?
// 0 = no switch
// 1 = OS203013MT7QN1 on meltable posts
// 2 = OS203013MT7QN1 and M2.5x8 wafer or pan head screws
switch_mount = (make == "top") ? 2 : 1 ;

// Printing process: "FDM", "SLS"
// The ID of screw holes needs to be adjusted depending on whether the model is printed by FDM or SLS.
// Holes come out slightly undersized with FDM. A hole the right size for a given screw when printed by FDM, will be too large when printed by SLS.
// So this setting adjusts the ID of screw holes to be optimal for the specified printing method.
printing_process = "FDM"; // FDM or SLS, adjusts ID of screw holes

include_text = (printing_process=="SLS") ? true : false;

explode_seperation = 30;
wall_thickness = 1;

text_depth = 0.2;
text_size_1 = 3.2;
text_size_2 = 5.5;

fc = 0.2;  // fitment clearance
inner_corner_h = 6;  // main shell inside corner horizontal radius
inner_corner_v = 2;  // main shell inside corner vertical radius
df = 1;  // default fillet

// holes for M3 screws, but note that screws are not required
pcb_mount_screw_d = 3;
pcb_mount_post_id_fdm = pcb_mount_screw_d * 0.85;
pcb_mount_post_id_sls = pcb_mount_screw_d * 0.8;
pcb_mount_post_id = (printing_process=="SLS") ? pcb_mount_post_id_sls : pcb_mount_post_id_fdm;

// thickness of the material around the pcb mounting screws - sets the screw post OD
pcb_mount_post_wall = 1.8;
pcb_mount_post_od = pcb_mount_post_id + pcb_mount_post_wall*2;

// arc smoothness
$fs = 0.2;
$fa = 1;

// To create pcb.stl:
//  KiCad pcbnew:
//    properties on DE0-Nano virtual component, 3d models, un-check all 3d models except DE0-Nano_bare
//    file, export, STEP, out/rgb2vga.pcb.step
//  FreeCAD: import rgb2vga.pcb.step, export STL Mesh, rgb2vga.pcb.stl
// Both files are huge, exclude from git.
pcb_model_stl = "../pcb/out/rgb2vga.pcb.stl";

pcb_thickness = 1.6;
space_above = 4;       // rgb2vga pcb top to inside wall ceiling
space_between = 11.25; // de0nano pcb top to rgb2vga pcb bottom
space_below = 10;      // inside wall floor to de0nano pcb bottom

// difference between de0-nano center and rgb2vga center
pcb_centers_offset = 2.7;   // from pcbnew

de0nano_pcb_length = 75.4;
de0nano_pcb_width = 49.2;
de0nano_pcb_elev = space_below;
de0nano_pcb_mount_l = 68.6; // from pcbnew
de0nano_pcb_mount_w = 42.4; // from pcbnew

rgb2vga_pcb_length = 70.48; // from pcbnew
rgb2vga_pcb_width = 55.88;  // from pcbnew
rgb2vga_pcb_corner = 3.175; // from pcbnew
rgb2vga_pcb_elev = de0nano_pcb_elev + pcb_thickness + space_between;

port_gap = 1; // gap around port connectors
port_corner = port_gap; // inside corner radius around port connectors

inner_height = space_below + pcb_thickness + space_between + pcb_thickness + space_above;
outer_height = wall_thickness + inner_height + wall_thickness;

pcb_model_elev = rgb2vga_pcb_elev;

// LENGTH - outer length flush with rgb2vga pcb length
outer_length = rgb2vga_pcb_length; // outside flush with rgb2vga pcb
inner_length = outer_length - wall_thickness - wall_thickness;

// WIDTH - inner width larger than de0-nano pcb length
inner_width = fc + de0nano_pcb_length + fc; // inside fit to de0-nano pcb
outer_width = wall_thickness + inner_width + wall_thickness;

window_height = 28;
window_width = 23.5;
window_corner = 2;
window_pos_x = -5.3;
window_pos_y = 6.505;

usb_width = 7.8;
usb_height = 4.1;
usb_gap = 1 + port_gap;
usb_corner = max(0.1,usb_gap);

hd15_height = 13;
ports_width = rgb2vga_pcb_width - 3.5;
ports_height = hd15_height + pcb_thickness;
ports_gap = fc;
ports_corner = 2;
ports_elev = rgb2vga_pcb_elev-ports_height/2+pcb_thickness;

split_elev = outer_height/2; // where to cut for top & bottom parts

// top/bottom clips
clip_width = 3;
clip_depth = 6;
clip_height = 4;
clip_detent = 1;
cdfc = 0.1; // fitment clearance for detent, different than fc

reg_post_width = 2;
reg_post_depth = 4;

top_ribs_loc = 18.85; // 18.85 inside, 21.7 gpio, 25.3 outside
top_ribs_width = 1;

rca_pin_l = 18.41;
rca_pin_i = 2.75;
rca_pin_r = 1.8;
rca_pin_h = 3;

// slide switch mounted on enclosure
// switch model C&K OS203013MT7QN1
sw_model_stl = "ref/CK_OS203013MT7QN1.stl";

// mounting method 1 - meltable posts
sw_sheet_thickness = 0.5;
sw_body_z = 10;
sw_body_tl = 24;
sw_body_l = 14.2;
sw_body_ml = 12.6;
sw_pos_x = 0;
sw_pos_y = sw_sheet_thickness - inner_width/2 + fc;
sw_pos_z = outer_height - wall_thickness - sw_body_z/2 - df/2 - fc;
sw_hole_l = 9.7;
sw_hole_h = 4.3;
sw1_post_height = 2; // how much meltable post over flange surface
sw1_post_dx = 2.8; // post oval width
sw1_post_dz = 4.4; // post oval length
sw1_post_mx = 17 / 2; // screw holes 17 center to center
sw_ear_setback = 2; // center front to wing rear, includes wing sw_sheet_thickness
sw_ear_z = 8.4;
sw_ear_x = (sw_body_tl - sw_body_l) / 2;

sw_screw_d = 2.5;
sw_screw_l = 8;

// switch mount 3 - M2.5x8 wafer head screws
// extra wide wafer head 5.5mm
// https://www.metricscrews.us/index.php?main_page=product_info&cPath=98_6_48&products_id=138
//sw_screw_head_d = 5.75; // wafer head countersink diameter

// regular wafer head or pad head 4.5mm
// https://www.metricscrews.us/index.php?main_page=product_info&cPath=98_6_48&products_id=137
//sw_screw_head_d = 4.75; // wafer head countersink diameter

// pan head from digikey
// https://www.digikey.com/short/z03czhjt
sw_screw_head_d = 5;

sw_screw_head_t = 0.5; // wafer head countersink depth

// printed nuts specifically to fit the switch
// height must be the full switch body width or greater
// so that the edge of the nut catches the sheet-metal
// switch body
sw_nut_thickness = 4;
sw_nut_width = (sw_body_tl-sw_body_ml)/2;
sw_nut_height = sw_body_z;
sw_nut_chamfer = 0.5;
sw_nut_id_fdm = sw_screw_d * 0.95;
sw_nut_id_sls = sw_screw_d * 0.85;
sw_nut_id = (printing_process=="SLS") ? sw_nut_id_sls : sw_nut_id_fdm;


o = 0.01; // overlap / overcut - ensure union parts overlap and cuts cupletely cut

include <handy.scad>;

module de0nano_pcb_clearance () {
  l = fc + de0nano_pcb_length + fc;
  w = fc + de0nano_pcb_width + fc;
  h = fc + pcb_thickness + fc;
  translate([-w/2,-l/2,-fc+wall_thickness+de0nano_pcb_elev])
   cube([w,l,h]);
}

module rgb2vga_pcb_clearance (tall=true) {
  h = (tall) ? rgb2vga_pcb_elev+pcb_thickness+fc : fc+pcb_thickness+fc ;
  e = (tall) ? wall_thickness : wall_thickness+rgb2vga_pcb_elev-fc ;
  translate([0,pcb_centers_offset,e])
   hull()
    mirror_copy([0,1,0])
     translate([0,rgb2vga_pcb_width/2-rgb2vga_pcb_corner,0])
      mirror_copy([1,0,0])
       translate([rgb2vga_pcb_length/2-rgb2vga_pcb_corner,0,0])
        cylinder(h=h,r=rgb2vga_pcb_corner+fc);
}

module main_ports () {
  pw = (ports_gap+ports_width+ports_gap)/2-ports_corner;
  ph = (ports_gap+ports_height+ports_gap)/2-ports_corner;
  translate([-outer_length/2-o,pcb_centers_offset,wall_thickness+ports_elev])
   rotate([90,0,90])
    hull()
     mirror_copy([0,1,0])
      translate([0,ph,0])
       mirror_copy([1,0,0])
        translate([pw,0,0])
         cylinder(h=o+outer_length+o,r=ports_corner);
}

module usb_port () {
  w = (usb_gap+usb_width+usb_gap)/2-usb_corner;
  h = (usb_gap+usb_height+usb_gap)/2-usb_corner;
  translate([-11.5,-outer_width/2-o,wall_thickness+de0nano_pcb_elev+pcb_thickness+usb_height/2])
   rotate([-90,0,0])
    hull()
     mirror_copy([0,1,0])
      translate([0,h,0])
       mirror_copy([1,0,0])
        translate([w,0,0])
         cylinder(h=o+wall_thickness+o,r=usb_corner);
}

module rca_pin_clearance() {
  translate([rgb2vga_pcb_length/2-rca_pin_i,rca_pin_l+pcb_centers_offset,wall_thickness+rgb2vga_pcb_elev+pcb_thickness+rca_pin_h/2-o])
   cylinder(h=rca_pin_h/2,r1=rca_pin_r+fc,r2=(rca_pin_r+fc)/2);
  translate([rgb2vga_pcb_length/2-rca_pin_i,rca_pin_l+pcb_centers_offset,wall_thickness+rgb2vga_pcb_elev+pcb_thickness])
   cylinder(h=rca_pin_h/2,r=rca_pin_r+fc);
}
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

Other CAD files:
enclosure/handy.scad

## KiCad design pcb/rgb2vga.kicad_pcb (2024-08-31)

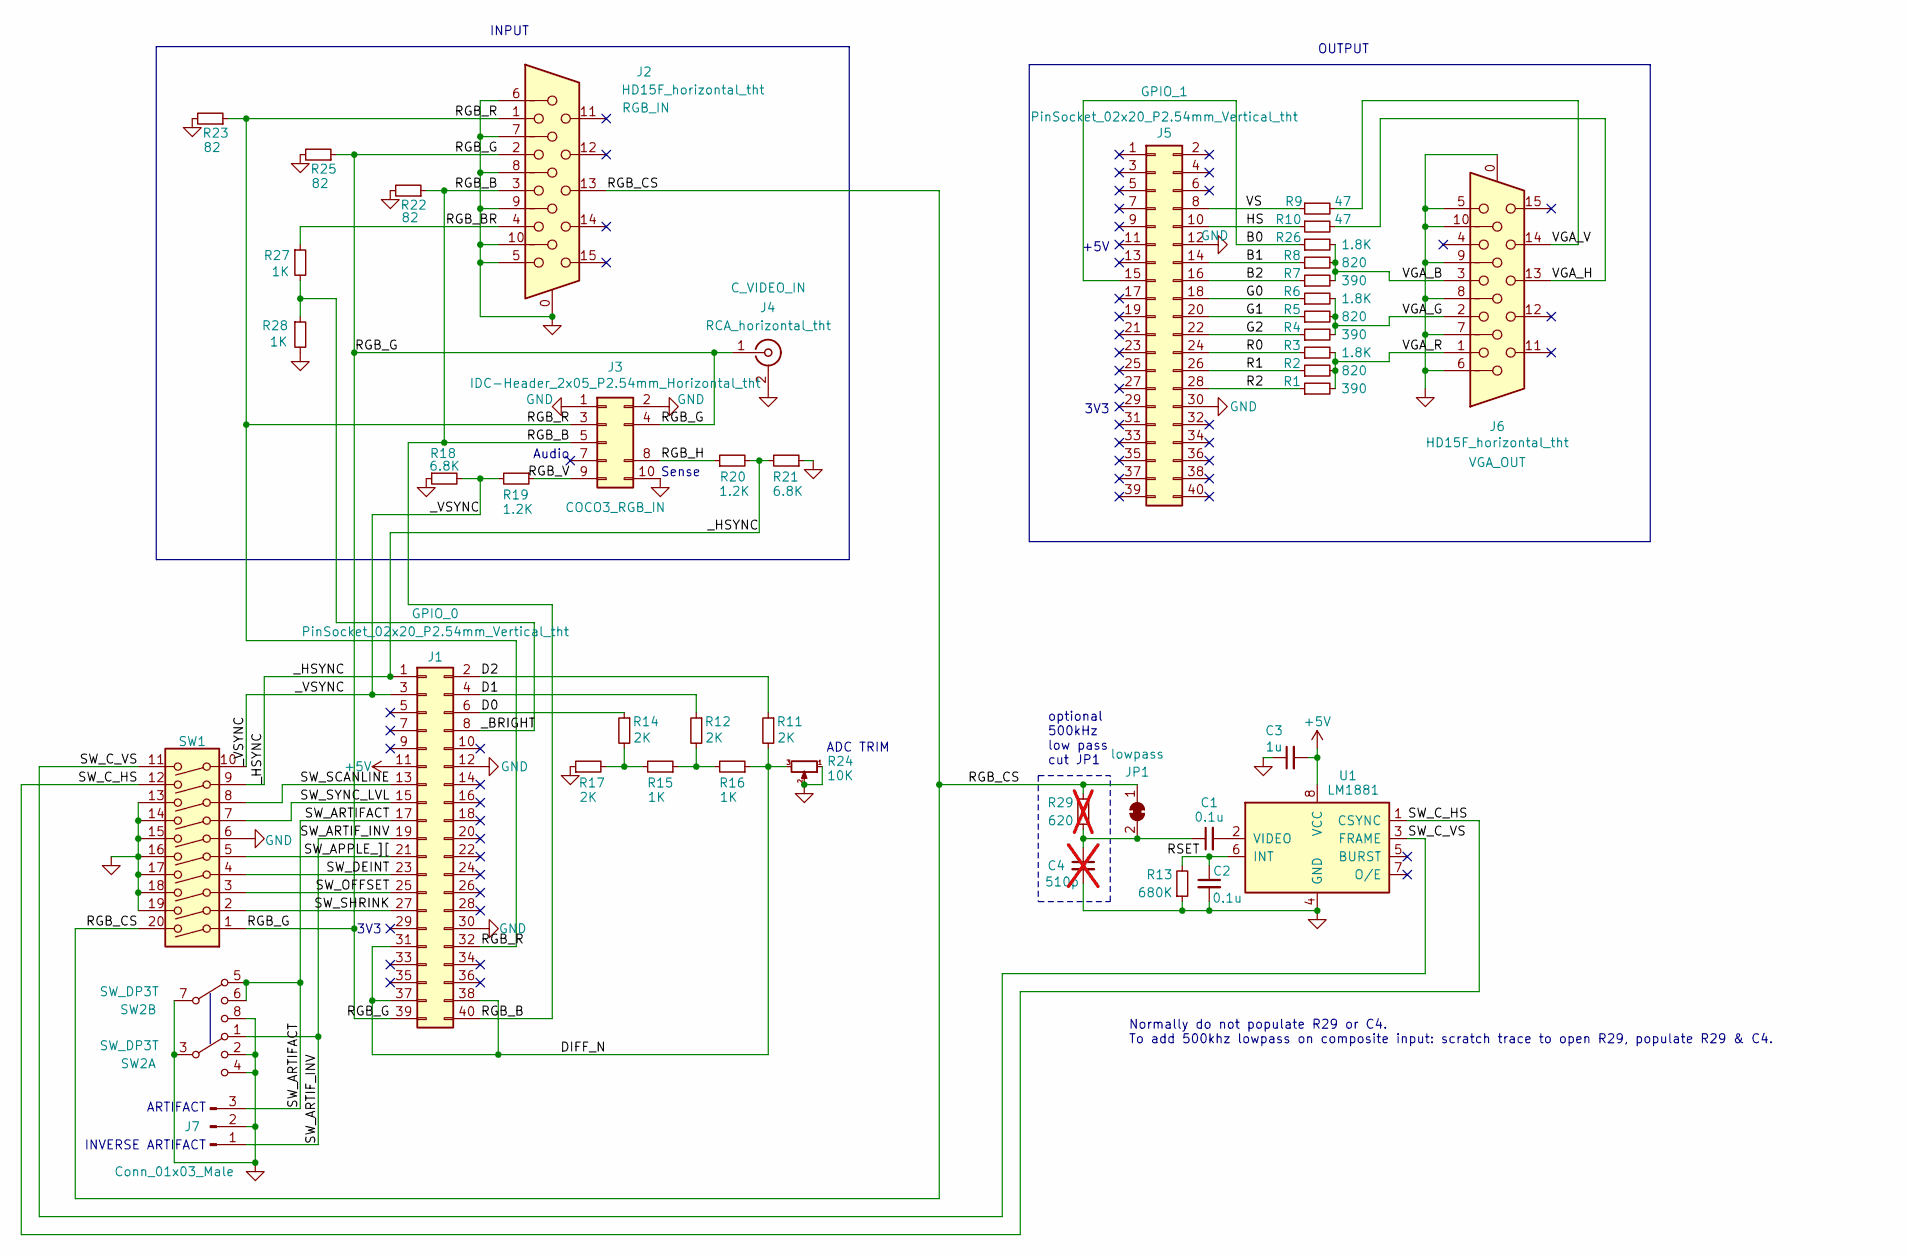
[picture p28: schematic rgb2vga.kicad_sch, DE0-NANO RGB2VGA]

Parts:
C1, C2: 0.1u; C_0805; MPN KGM21NR71H104JT
C3: 1u; C_0805; MPN CL21B105KAFNNNE
C4: 510p; C_0805; MPN C0805C511F3HAC7800; not fitted
J1, J5: PinSocket_02x20_P2.54mm_Vertical_tht; PinSocket_2x20_P2.54mm_Polarized_Vertical; MPN SFH11-PBPC-D20-ST-BK
J2, J6: HD15F_horizontal_tht; HD15-SN-25; MPN HD15-SN-25
J3: IDC-Header_2x05_P2.54mm_Horizontal_tht; IDC-Header_2x05_P2.54mm_Horizontal COCO3 KEYED; MPN 302-R101
J4: RCA_horizontal_tht; RCA; MPN RCJ-014
J7: Conn_01x03_Male; PinHeader_1x03_P2.54mm_Horizontal; MPN PRPC003SBAN-M71RC
JP1: lowpass; JP_0805
R1, R4, R7: 390; R_0805; MPN ERA-6AEB391V
R2, R5, R8: 820; R_0805; MPN ERA-6AEB821V
R3, R6, R26: 1.8K; R_0805; MPN ERA-6AEB182V
R9, R10: 47; R_0805; MPN ERA-6AEB470V
R11, R12, R14, R17: 2K; R_0805; MPN ERA-6AEB202V
R13: 680K; R_0805; MPN ERA-6AEB684V
R15, R16, R27, R28: 1K; R_0805; MPN ERA-6AEB102V
R18, R21: 6.8K; R_0805; MPN ERA-6AEB682V
R19, R20: 1.2K; R_0805; MPN ERA-6AEB122V
R22, R23, R25: 82; R_0805; MPN ERA-6AEB820V
R24: 10K; Potentiometer_Bourns_3006P_Horizontal; MPN 3006P-1-103LF
R29: 620; R_0805; MPN ERA-6AEB621V; not fitted
SW1: SW_DIP_x10; SW_DIP_SPSTx10_Slide_6.7_8.61_P2.54_LowProfile; MPN DS04-254-2-10BK-SMT
SW2: SW_DP3T; SW_DP3T_CK_JS203011JAQN; MPN CL-SB-23A-11T
U1: LM1881; SOIC-8_4x5; MPN LM1881MX/NOPB

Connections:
+5V: C3.2, J1.11, U1.8 (VCC)
/B0: J5.15, R26.1
/B1: J5.14, R8.1
/B2: J5.16, R7.1
/D0: J1.6, R14.1
/D1: J1.4, R12.1
/D2: J1.2, R11.1
/DIFF_N: J1.31, J1.37, J1.38, R11.2, R16.1, R24.3
/G0: J5.18, R6.1
/G1: J5.20, R5.1
/G2: J5.22, R4.1
/HS: J5.10, R10.1
/R0: J5.24, R3.1
/R1: J5.26, R2.1
/R2: J5.28, R1.1
/RGB_B: J1.40, J2.3, J3.5, R22.1
/RGB_BR: J2.4, R27.1
/RGB_CS: J2.13, JP1.1 (A), R29.1, SW1.20
/RGB_G: J1.39, J2.2, J3.4, J4.1 (In), R25.1, SW1.1
/RGB_H: J3.8, R20.1
/RGB_R: J1.32, J2.1, J3.3, R23.1
/RGB_V: J3.9, R19.1
/RSET: C2.1, R13.2, U1.6 (INT)
/SW_APPLE_][: J1.21, SW1.5
/SW_ARTIFACT: J1.17, J7.3, SW2.5, SW2.6
/SW_ARTIF_INV: J1.19, J7.1, SW2.1
/SW_C_HS: SW1.12, U1.1 (CSYNC)
/SW_C_VS: SW1.11, U1.3 (FRAME)
/SW_DEINT: J1.23, SW1.4
/SW_OFFSET: J1.25, SW1.3
/SW_SCANLINE: J1.13, SW1.8
/SW_SHRINK: J1.27, SW1.2
/SW_SYNC_LVL: J1.15, SW1.7
/VGA_B: J6.3, R7.2, R8.2, R26.2
/VGA_G: J6.2, R4.2, R5.2, R6.2
/VGA_H: J6.13, R10.2
/VGA_R: J6.1, R1.2, R2.2, R3.2
/VGA_V: J6.14, R9.2
/VS: J5.8, R9.1
/_BRIGHT: J1.8, R27.2, R28.1
/_HSYNC: J1.1, R20.2, R21.2, SW1.9
/_VSYNC: J1.3, R18.2, R19.2, SW1.10
GND: C2.2, C3.1, C4.2, J1.12, J1.30, J2.0, J2.5, J2.6, J2.7, J2.8, J2.9, J2.10, J3.1, J3.2, J3.10, J4.2 (Ext), J5.12, J5.30, J6.0, J6.5, J6.6, J6.7, J6.8, J6.9, J6.10, J7.2, R13.1, R17.1, R18.1, R21.1, R22.2, R23.2, R24.1, R24.2, R25.2, R28.2, SW1.6, SW1.13, SW1.14, SW1.15, SW1.16, SW1.17, SW1.18, SW1.19, SW2.2, SW2.3, SW2.4, SW2.7, SW2.8, U1.4 (GND)
unnamed: C1.1, C4.1, JP1.2 (B), R29.2
unnamed: R12.2, R15.1, R16.2
unnamed: R14.2, R15.2, R17.2
unnamed: C1.2, U1.2 (VIDEO)

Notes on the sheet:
Normally do not populate R29 or C4. To add 500khz lowpass on composite input: scratch trace to open R29, populate R29 & C4.
Audio
3V3
ARTIFACT
INPUT
OUTPUT
Sense
optional 500kHz low pass cut JP1
+5V
ADC TRIM
INVERSE ARTIFACT

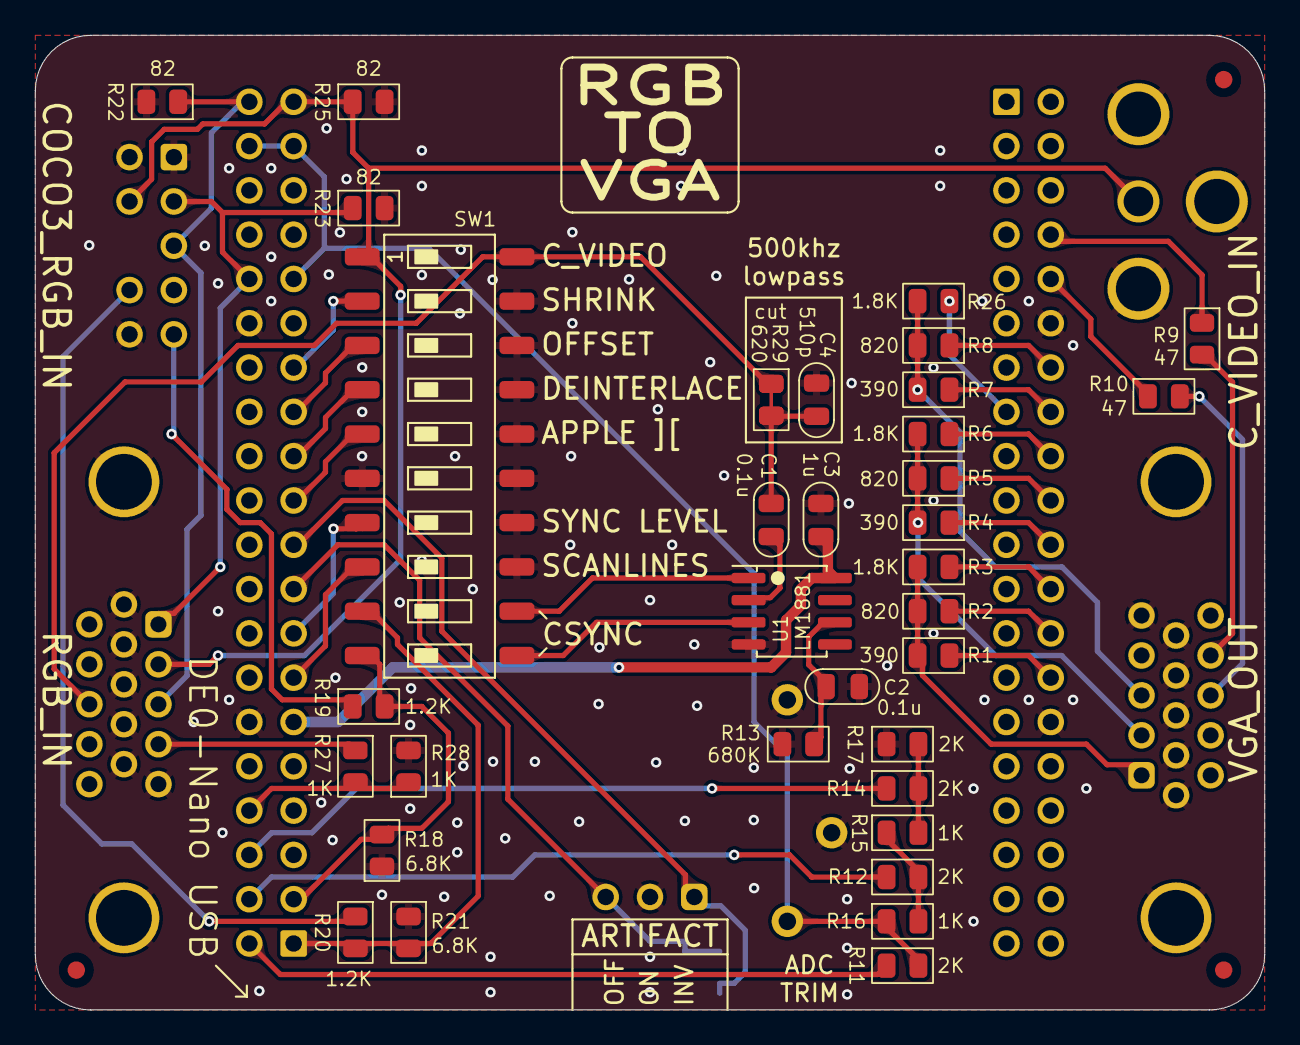
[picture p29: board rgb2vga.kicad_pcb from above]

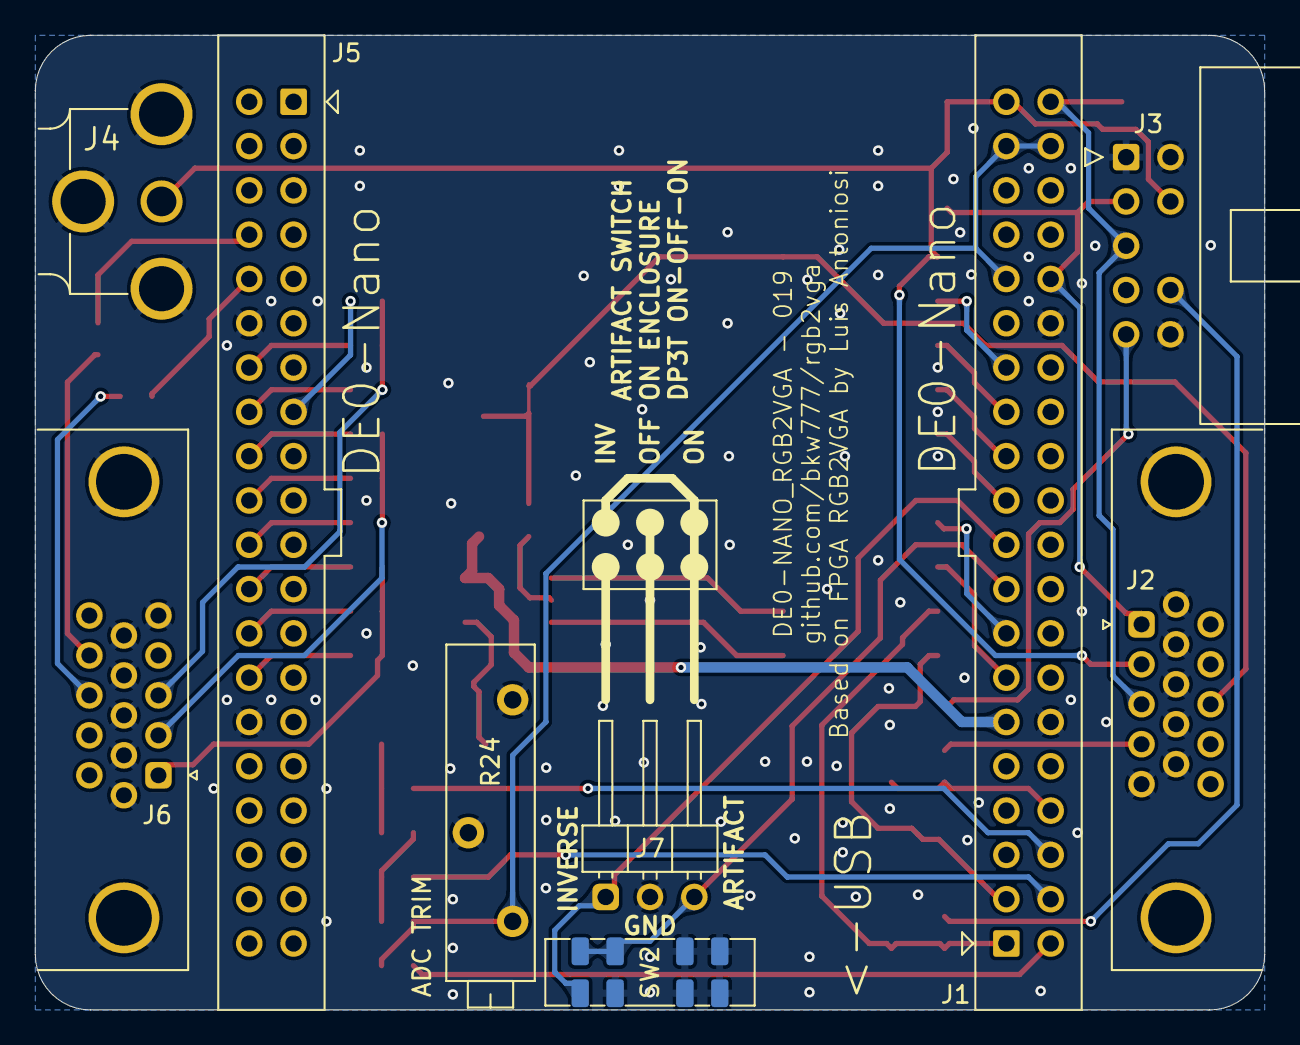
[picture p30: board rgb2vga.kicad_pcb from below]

Board: 2 copper layers, 70.5 x 55.9 mm, 45 parts (9 on the bottom side), 47 nets.

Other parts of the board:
DE0-Nano: DE0-Nano_bare

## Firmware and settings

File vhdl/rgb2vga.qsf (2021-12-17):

set_location_assignment PIN_R8 -to CLOCK_50
set_location_assignment PIN_L4 -to DRAM_ADDR[12]
set_location_assignment PIN_N1 -to DRAM_ADDR[11]
set_location_assignment PIN_N2 -to DRAM_ADDR[10]
set_location_assignment PIN_P1 -to DRAM_ADDR[9]
set_location_assignment PIN_R1 -to DRAM_ADDR[8]
set_location_assignment PIN_T6 -to DRAM_ADDR[7]
set_location_assignment PIN_N8 -to DRAM_ADDR[6]
set_location_assignment PIN_T7 -to DRAM_ADDR[5]
set_location_assignment PIN_P8 -to DRAM_ADDR[4]
set_location_assignment PIN_M8 -to DRAM_ADDR[3]
set_location_assignment PIN_N6 -to DRAM_ADDR[2]
set_location_assignment PIN_N5 -to DRAM_ADDR[1]
set_location_assignment PIN_P2 -to DRAM_ADDR[0]
set_location_assignment PIN_M6 -to DRAM_BA[1]
set_location_assignment PIN_M7 -to DRAM_BA[0]
set_location_assignment PIN_L1 -to DRAM_CAS_N
set_location_assignment PIN_L7 -to DRAM_CKE
set_location_assignment PIN_R4 -to DRAM_CLK
set_location_assignment PIN_P6 -to DRAM_CS_N
set_location_assignment PIN_K1 -to DRAM_DQ[15]
set_location_assignment PIN_N3 -to DRAM_DQ[14]
set_location_assignment PIN_P3 -to DRAM_DQ[13]
set_location_assignment PIN_R5 -to DRAM_DQ[12]
set_location_assignment PIN_R3 -to DRAM_DQ[11]
set_location_assignment PIN_T3 -to DRAM_DQ[10]
set_location_assignment PIN_T2 -to DRAM_DQ[9]
set_location_assignment PIN_T4 -to DRAM_DQ[8]
set_location_assignment PIN_R7 -to DRAM_DQ[7]
set_location_assignment PIN_J1 -to DRAM_DQ[6]
set_location_assignment PIN_J2 -to DRAM_DQ[5]
set_location_assignment PIN_K2 -to DRAM_DQ[4]
set_location_assignment PIN_K5 -to DRAM_DQ[3]
set_location_assignment PIN_L8 -to DRAM_DQ[2]
set_location_assignment PIN_G1 -to DRAM_DQ[1]
set_location_assignment PIN_G2 -to DRAM_DQ[0]
set_location_assignment PIN_T5 -to DRAM_DQM[1]
set_location_assignment PIN_R6 -to DRAM_DQM[0]
set_location_assignment PIN_L2 -to DRAM_RAS_N
set_location_assignment PIN_C2 -to DRAM_WE_N
set_location_assignment PIN_B8 -to VSYNC
set_location_assignment PIN_A8 -to HSYNC
set_location_assignment PIN_T12 -to VGAVS
set_location_assignment PIN_K16 -to VGAG2
set_location_assignment PIN_L15 -to VGAR0
set_location_assignment PIN_P16 -to VGAR1
set_location_assignment PIN_N16 -to VGAR2
set_location_assignment PIN_P9 -to VGAG0
set_location_assignment PIN_N11 -to VGAG1
set_location_assignment PIN_P11 -to VGAB0
set_location_assignment PIN_R11 -to VGAB1
set_location_assignment PIN_T11 -to VGAHS
set_location_assignment PIN_A3 -to D0
set_location_assignment PIN_C3 -to D1
set_location_assignment PIN_D3 -to D2
set_instance_assignment -name IO_STANDARD "BUS LVDS" -to DIFFB
set_instance_assignment -name IO_STANDARD "BUS LVDS" -to DIFFG
set_instance_assignment -name IO_STANDARD "BUS LVDS" -to DIFFR
set_instance_assignment -name IO_STANDARD "BUS LVDS" -to DIFFBn
set_instance_assignment -name IO_STANDARD "BUS LVDS" -to DIFFGn
set_instance_assignment -name IO_STANDARD "BUS LVDS" -to DIFFRn
set_location_assignment PIN_B12 -to DIFFB
set_location_assignment PIN_A12 -to DIFFBn
set_location_assignment PIN_D12 -to DIFFG
set_location_assignment PIN_D11 -to DIFFGn
set_location_assignment PIN_D9 -to DIFFR
set_location_assignment PIN_C9 -to DIFFRn
set_location_assignment PIN_A5 -to FP0
set_location_assignment PIN_B6 -to FP1
set_location_assignment PIN_B7 -to FP2
set_location_assignment PIN_A7 -to FP3
set_location_assignment PIN_C8 -to FP4
set_location_assignment PIN_E7 -to FP5
set_location_assignment PIN_E8 -to FP6
set_location_assignment PIN_F9 -to FP7
set_location_assignment PLL_1 -to "pll_speccy:pll_inst"
set_location_assignment PLL_1 -to "pll_coco3:pll_inst"
set_location_assignment PIN_R10 -to VGAB2
set_location_assignment PIN_B4 -to BRIGHT
set_instance_assignment -name CURRENT_STRENGTH_NEW "MINIMUM CURRENT" -to D0
set_instance_assignment -name CURRENT_STRENGTH_NEW "MINIMUM CURRENT" -to D1
set_instance_assignment -name CURRENT_STRENGTH_NEW "MINIMUM CURRENT" -to D2
set_instance_assignment -name CURRENT_STRENGTH_NEW "MINIMUM CURRENT" -to DIFFB
set_instance_assignment -name CURRENT_STRENGTH_NEW "MINIMUM CURRENT" -to DIFFBn
set_instance_assignment -name CURRENT_STRENGTH_NEW "MINIMUM CURRENT" -to DIFFG
set_instance_assignment -name CURRENT_STRENGTH_NEW "MINIMUM CURRENT" -to DIFFGn
set_instance_assignment -name CURRENT_STRENGTH_NEW "MINIMUM CURRENT" -to DIFFR
set_instance_assignment -name CURRENT_STRENGTH_NEW "MINIMUM CURRENT" -to DIFFRn
set_instance_assignment -name CURRENT_STRENGTH_NEW "MINIMUM CURRENT" -to FP0
set_instance_assignment -name CURRENT_STRENGTH_NEW "MINIMUM CURRENT" -to FP1
set_instance_assignment -name CURRENT_STRENGTH_NEW "MINIMUM CURRENT" -to FP2
set_instance_assignment -name CURRENT_STRENGTH_NEW "MINIMUM CURRENT" -to FP3
set_instance_assignment -name CURRENT_STRENGTH_NEW "MINIMUM CURRENT" -to FP4
set_instance_assignment -name CURRENT_STRENGTH_NEW "MINIMUM CURRENT" -to FP5
set_instance_assignment -name CURRENT_STRENGTH_NEW "MINIMUM CURRENT" -to FP6
set_instance_assignment -name CURRENT_STRENGTH_NEW "MINIMUM CURRENT" -to FP7
set_instance_assignment -name CURRENT_STRENGTH_NEW "MINIMUM CURRENT" -to HSYNC
set_instance_assignment -name CURRENT_STRENGTH_NEW "MINIMUM CURRENT" -to VGAB0
set_instance_assignment -name CURRENT_STRENGTH_NEW "MINIMUM CURRENT" -to VGAB1
set_instance_assignment -name CURRENT_STRENGTH_NEW "MINIMUM CURRENT" -to VGAG0
set_instance_assignment -name CURRENT_STRENGTH_NEW "MINIMUM CURRENT" -to VGAG1
set_instance_assignment -name CURRENT_STRENGTH_NEW "MINIMUM CURRENT" -to VGAG2
set_instance_assignment -name CURRENT_STRENGTH_NEW "MINIMUM CURRENT" -to VGAHS
set_instance_assignment -name CURRENT_STRENGTH_NEW "MINIMUM CURRENT" -to VGAR0
set_instance_assignment -name CURRENT_STRENGTH_NEW "MINIMUM CURRENT" -to VGAR1
set_instance_assignment -name CURRENT_STRENGTH_NEW "MINIMUM CURRENT" -to VGAR2
set_instance_assignment -name CURRENT_STRENGTH_NEW "MINIMUM CURRENT" -to VGAVS
set_instance_assignment -name CURRENT_STRENGTH_NEW "MINIMUM CURRENT" -to VSYNC
set_instance_assignment -name WEAK_PULL_UP_RESISTOR ON -to FP0
set_instance_assignment -name WEAK_PULL_UP_RESISTOR ON -to FP1
set_instance_assignment -name WEAK_PULL_UP_RESISTOR ON -to FP2
set_instance_assignment -name WEAK_PULL_UP_RESISTOR ON -to FP3
set_instance_assignment -name WEAK_PULL_UP_RESISTOR ON -to FP4
set_instance_assignment -name WEAK_PULL_UP_RESISTOR ON -to FP5
set_instance_assignment -name WEAK_PULL_UP_RESISTOR ON -to FP6
set_instance_assignment -name WEAK_PULL_UP_RESISTOR ON -to FP7
set_instance_assignment -name CURRENT_STRENGTH_NEW "MINIMUM CURRENT" -to VGAB2
set_instance_assignment -name CURRENT_STRENGTH_NEW "MINIMUM CURRENT" -to BRIGHT
set_global_assignment -name FAMILY "Cyclone IV E"
set_global_assignment -name DEVICE EP4CE22F17C6
set_global_assignment -name TOP_LEVEL_ENTITY rgb2vga
set_global_assignment -name ORIGINAL_QUARTUS_VERSION 13.0
set_global_assignment -name PROJECT_CREATION_TIME_DATE "22:47:32  SEPTEMBER 22, 2014"
set_global_assignment -name LAST_QUARTUS_VERSION "21.1.0 Lite Edition"
set_global_assignment -name PROJECT_OUTPUT_DIRECTORY output_files
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

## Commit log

2021-11-01 resistor values, routing
    [rgb2vga.kicad_pcb]
2021-11-05 recreated schematic, add rgbi resistors, 3d models, digikey bom, Roger Taylor resistor values
    [DE0-Nano_RGB2VGA.BOM.csv, rgb2vga.kicad_pcb, rgb2vga.sch]
2021-11-05 schematic in readme
2021-11-05 add some net labels and fix several errors in the schematic didn't match the pcb
    [rgb2vga.kicad_pcb, rgb2vga.sch]
2021-11-05 readme schematic
2021-11-05 remove accidental junction on DIFFB
    [rgb2vga.sch]
2021-11-05 spread schematic out a little
    [rgb2vga.kicad_pcb, rgb2vga.sch]
2021-11-05 neaten schematic
    [rgb2vga.sch]
2021-11-06 net labels
    [rgb2vga.kicad_pcb, rgb2vga.sch]
2021-11-06 move caps near lm1881
    [rgb2vga.kicad_pcb, rgb2vga.sch]
2021-11-07 layout grid alignmen
    [rgb2vga.kicad_pcb, rgb2vga.sch]
2021-11-07 link schematic to pcb, remove unused footprints and models
    [rgb2vga.kicad_pcb, rgb2vga.sch]
2021-11-07 slight pcb touchup
    [rgb2vga.kicad_pcb]
2021-11-07 rearrange R22 R25
    [rgb2vga.kicad_pcb]
2021-11-07 better 3d model for vga connector
    [rgb2vga.kicad_pcb, rgb2vga.sch]
2021-11-10 vga connector 3d model
2021-11-10 move R26
    [rgb2vga.kicad_pcb]
2021-11-12 fix spacing between GPIO0 and GPIO1
    [rgb2vga.kicad_pcb]
2021-11-15 zone fill to new pcb edge
    [rgb2vga.kicad_pcb]
2021-11-16 gpio_1 position
    [rgb2vga.kicad_pcb, rgb2vga.sch]
2021-11-16 traces and pours around gpio_1
    [rgb2vga.kicad_pcb]
2021-11-18 add DE0-Nano virtual component
    [rgb2vga.kicad_pcb]
2021-11-19 low profile version
    [DE0-Nano_RGB2VGA.BOM.csv, rgb2vga.kicad_pcb, rgb2vga.sch]
2021-11-19 renders, small routing touchup
    [rgb2vga.kicad_pcb]
2021-11-19 gpio headers must be 43.4mm apart
    [rgb2vga.kicad_pcb]
2021-11-19 v002.1 - gpio headers must be 43.4mm apart
    [rgb2vga.kicad_pcb]
2021-11-23 kicad gitignore
2021-11-23 remove quartus output files from git
    [rgb2vga.smp_dump.txt]
2021-11-26 update from main
    [rgb2vga.smp_dump.txt]
2021-11-26 net names, clearance for idc plugs around gpio headers
    [rgb2vga.kicad_pcb, rgb2vga.sch]
2021-11-28 SW2 for Artifact
    [DE0-Nano_RGB2VGA.BOM.csv, rgb2vga.kicad_pcb, rgb2vga.sch]
2021-11-29 align & center parts, silkscreen
    [rgb2vga.kicad_pcb, rgb2vga.sch]
2021-12-01 isolisolate r,g,b in a little better, cosmetic alignment
    [rgb2vga.kicad_pcb, rgb2vga.scad, rgb2vga.sch]
2021-12-11 exclude 3d models except in footprints
2021-12-11 remote artifact sw
    [rgb2vga.kicad_pcb, rgb2vga.sch]
2021-12-11 exclude 3d models outside of footprints
2021-12-11 3d printable enclosure
    [rgb2vga.scad]
2021-12-11 case doesn't fit v003
    [rgb2vga.scad]
2021-12-11 add 3d-printable enclosure
    [rgb2vga.scad]
2021-12-11 remove accidentally added case dir, again
    [rgb2vga.scad]
2021-12-14 better enclosure
    [fillet_circle.scad, rgb2vga.kicad_pcb, rgb2vga.scad]
2021-12-14 update 3d print link
2021-12-14 enclosure render
2021-12-16 case rounded box & fillets
    [fillet_circle.scad, handy.scad, rgb2vga.scad]
2021-12-16 readme, enclosure 009.3 craftcloud
2021-12-17 add 3-pin header to bom csv
    [DE0-Nano_RGB2VGA.BOM.csv]
2021-12-17 silkscreen for off-board artifact switch
    [rgb2vga.kicad_pcb]
2021-12-17 move coco3 rgb port slightly. silkscreen
    [rgb2vga.kicad_pcb]
2021-12-28 port positions and silkscreen
    [rgb2vga.kicad_pcb, rgb2vga.sch]
2021-12-28 enclosure fillets
    [rgb2vga.scad]
2021-12-28 small schematic tidy
    [rgb2vga.sch]
2021-12-28 right-angle usb cable
    [DE0-Nano_RGB2VGA.BOM.csv]
2021-12-28 enclosure scad default view
    [rgb2vga.scad]
2022-01-02 enclosure artifact switch
    [DE0-Nano_RGB2VGA.BOM.csv, rgb2vga.kicad_pcb, rgb2vga.scad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]
2022-01-02 enclosure text
    [rgb2vga.scad]
2022-01-11 printed nuts bore diameter
    [rgb2vga.scad]
2022-01-19 nut dimensions, inhibit surface text for fdm
    [rgb2vga.scad]
2022-01-20 case v013, makefile, switch mount & nuts
    [handy.scad, rgb2vga.kicad_pcb, rgb2vga.sch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]
2022-01-20 remove flat-head screw option - conical head would split layers
    [rgb2vga_enclosure.scad]
2022-01-21 enclosure fit and configurable switch mount
    [rgb2vga_enclosure.scad]
2022-01-22 remove print profile
2023-02-27 kicad 6
    [rgb2vga.kicad_pcb, rgb2vga.kicad_sch, rgb2vga.sch]
2024-01-05 multi-turn DAC trimmer pot
    [DE0-Nano_RGB2VGA.BOM.csv, rgb2vga.kicad_pcb, rgb2vga.kicad_sch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]
2024-01-08 SMT passives, add lowpass, decouple lm1881
    [DE0-Nano_RGB2VGA.BOM.csv, DE0-Nano_RGB2VGA.THT.BOM.csv, rgb2vga.THT.kicad_pcb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]
2024-03-07 kicad 8
    [rgb2vga.kicad_pcb, rgb2vga.kicad_sch]
2024-07-26 fix bom had 680 instead of 680K for R13
    [DE0-Nano_RGB2VGA.BOM.csv, rgb2vga.kicad_pcb]
2024-07-26 fiducials, pics
    [rgb2vga.kicad_pcb, rgb2vga.kicad_sch]
2024-08-06 C4 510p, dnp fiducials, pnp export
    [DE0-Nano_RGB2VGA.BOM.csv, rgb2vga.kicad_pcb, rgb2vga.kicad_sch]
2024-08-07 export bom, centroid
    [rgb2vga.fab.bom.csv, rgb2vga.kicad_pcb, rgb2vga.kicad_sch]
2024-08-30 silkscreen & pics
    [rgb2vga.kicad_pcb, rgb2vga.kicad_sch]
2024-08-31 rename msx switch to offset
    [rgb2vga.kicad_pcb, rgb2vga.kicad_sch]
